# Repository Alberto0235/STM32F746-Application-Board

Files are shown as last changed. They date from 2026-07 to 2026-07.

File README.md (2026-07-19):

<div align="center">

# STM32F746ZG — Custom Application Board

**Custom-designed four-layer PCB built around the STM32F746ZGTx (LQFP-144) —
covering the full design cycle from hierarchical schematic capture to impedance-controlled layout and manufacturing outputs.**




[]()



*Alberto Marrone · Christian Schmitz · Leo Walter*
<br />
*Diseño de Circuitos Impresos (DCI) — UPV MUISE, June 2026*

<br/>

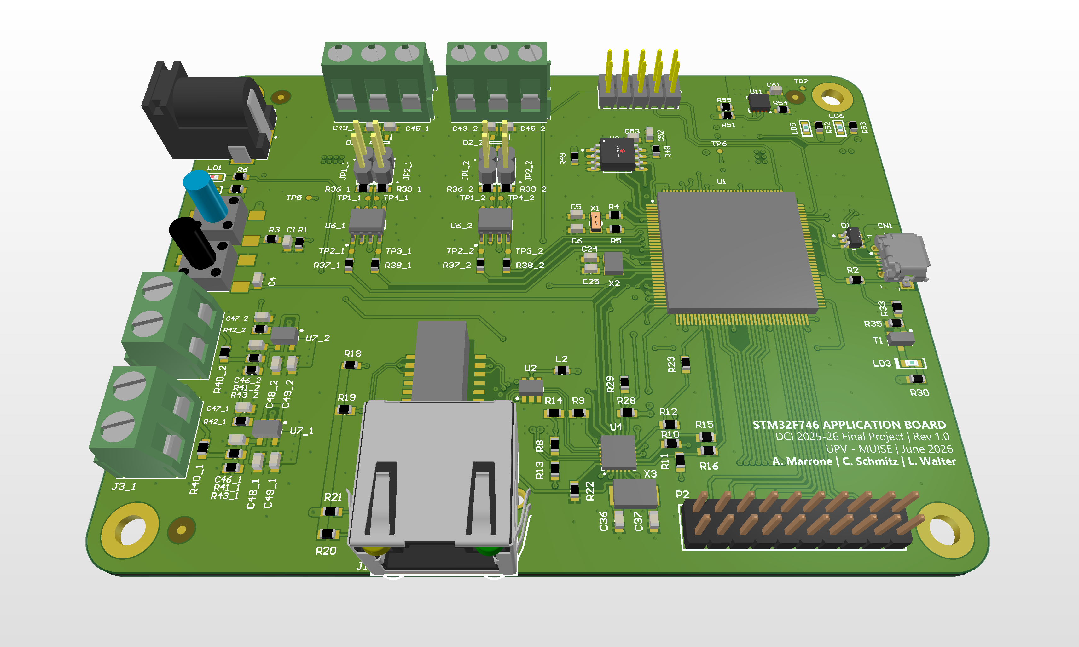
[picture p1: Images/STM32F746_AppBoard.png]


</div>

---

## Overview

This project documents the complete hardware design of a custom STM32F746ZGTx application board, derived from the [ST NUCLEO-F746ZG](https://www.st.com/en/evaluation-tools/nucleo-f746zg.html) reference design. The on-board ST-LINK debugger, Morpho/Zio expansion headers, and all peripherals not required by the project specification were removed. The remaining circuitry was redesigned and extended to implement all required interfaces on a custom four-layer PCB.

The design was carried out by a **three-person team** using **Altium Designer 26** with **Altium 365**, which provided real-time cloud-based concurrent editing, integrated version control, and design review workflows natively within the tool — enabling all three team members to work on the same project simultaneously without file conflicts.

> **Note:** This board was designed as an academic project and has not been fabricated or assembled. This repository is a static export of the completed design; the Altium 365 cloud workspace is not linked here.

---

## ⚙️ Interfaces

| Block | Implementation |
|---|---|
| **Microcontroller** | STM32F746ZGTx, LQFP-144, direct-solder |
| **Ethernet** | LAN8742A-CZ-TR PHY (RMII), KMS-1102NL magnetics, KRJ-CB4.2GYZNL RJ45 |
| **USB** | Micro-AB OTG FS (Molex 475900001), ESDA6V1BC6 ESD protection, STMPS2151STR VBUS switch |
| **CAN** | 2× CAN transceiver channels, switchable 120 Ω termination, complex hierarchy |
| **Analog inputs** | 2× 0–10 V → 3.3 V conditioning channels, MCP6021 op-amp, complex hierarchy, ADC3 |
| **SPI Flash** | SST26VF032BA-104I/SM, 32 Mbit (4 MB), SOIJ-8, SPI mode |
| **GPIO expansion** | Würth 61301621121, 2×8 100 mil pitch, 16 signals |
| **Debug** | TSW-105-07-G-D, 2×5 100 mil SWD + SWO connector |
| **Power input** | PJ-002A DC barrel jack (preferred) + USB VBUS fallback via TPS2113A mux |
| **5 V rail** | LD1117S50TR LDO from VIN |
| **3.3 V rail** | LD39050PU33R LDO from 5 V bus |
| **BOOT0** | 10 kΩ pull-down + tact switch to VDD for DFU bootloader entry |
| **Clocks** | 8 MHz HSE crystal (→ PLL, 216 MHz system / 48 MHz USB), 32.768 kHz LSE (RTC) |

---

## 🧩 Schematic Architecture

The schematic is organized as a **hierarchical multi-sheet design** in Altium. A single top-level sheet instantiates all functional blocks and defines the inter-block signal connections. The CAN transceiver and ADC signal-conditioning blocks use **complex hierarchy** — one sheet per block, instantiated twice, one per channel — as required by the project specification.

<p align="center">
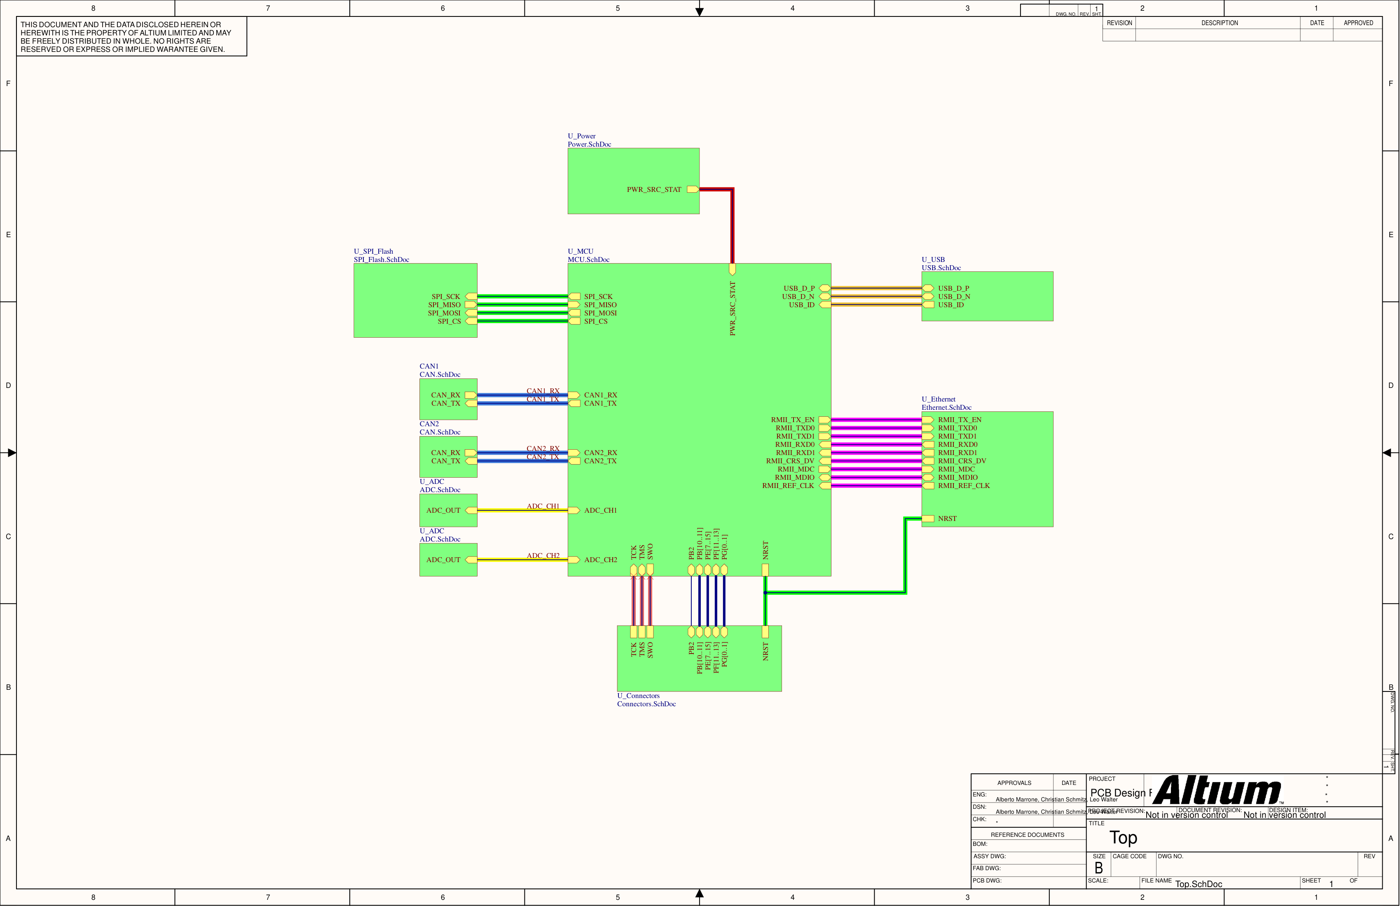
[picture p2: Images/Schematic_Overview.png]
  
</p>

### MCU Pin Allocation

Peripheral assignment was defined in STM32CubeMX and locked before schematic capture began.

<p align="center">
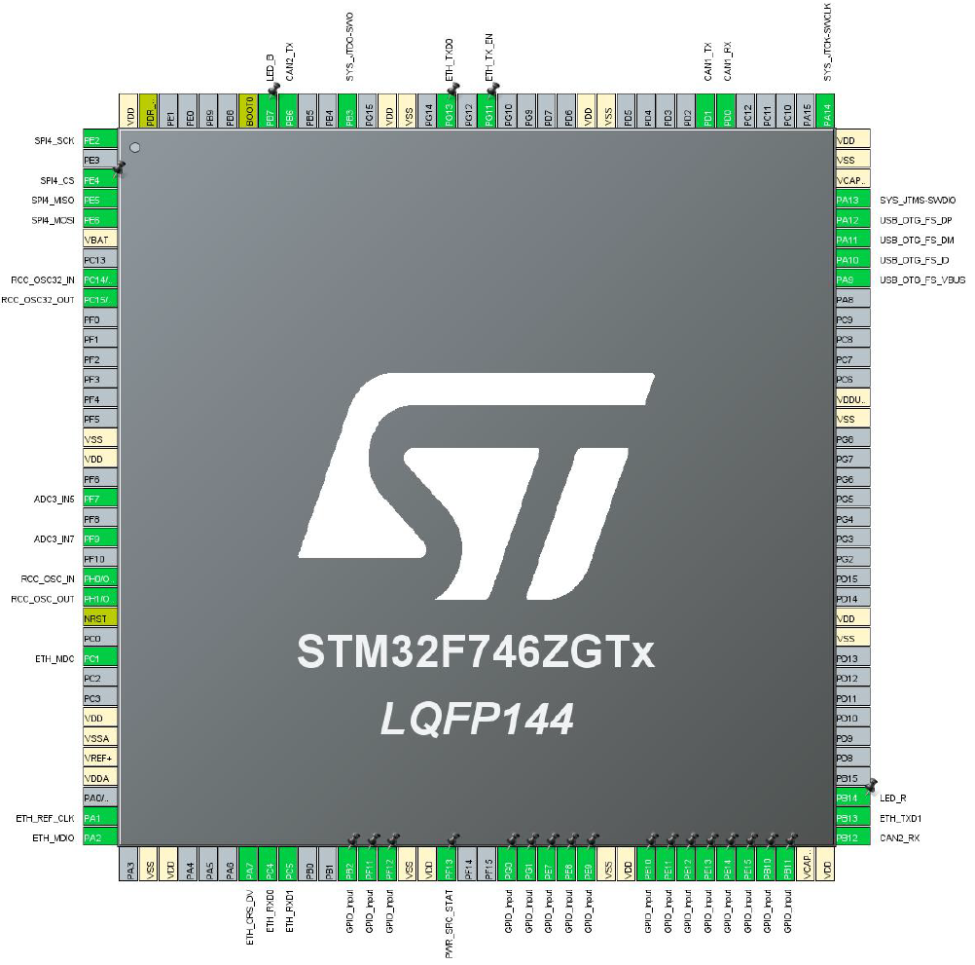
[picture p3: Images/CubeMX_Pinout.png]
  
</p>

| Peripheral | Pins |
|---|---|
| Ethernet RMII | PA1, PA2, PA7, PC1, PC4, PC5, PB13, PG11, PG13 |
| USB OTG FS | PA9 (VBUS), PA10 (ID), PA11 (DM), PA12 (DP) |
| CAN1 | PD0 (RX), PD1 (TX) |
| CAN2 | PB12 (RX), PB6 (TX) |
| SPI4 | PE2 (SCK), PE4 (CS), PE5 (MISO), PE6 (MOSI) |
| ADC3 | PF7 (IN5), PF9 (IN7) |
| SWD + SWO | PA13 (SWDIO), PA14 (SWDCLK), PB3 (SWO) |
| HSE | PH0, PH1 |
| LSE | PC14, PC15 |

The full clock tree configuration is documented in the [design report](Docs/DCI_Design_Report.pdf).

---

## 📐 PCB Stack-up

A four-layer stack-up was selected as a cost-effective balance between routing density and electrical performance. Thinner-than-standard prepregs (0.18 mm PP-021) bring the outer signal layers closer to their reference planes, yielding practical trace widths for the impedance profiles below — while keeping total board thickness within the 1.6 mm fabrication limit.

| Layer | Type | Material | Thickness | Role |
|---|---|---|---|---|
| **L1** | Signal | CF-004, 35 µm Cu | 0.04 mm | Critical signals — all high-speed components |
| | Prepreg | PP-021 | 0.18 mm | Thinned vs. standard for impedance |
| **L2** | GND Plane | CF-004, 35 µm Cu | 0.04 mm | Solid, unbroken — primary reference for L1 |
| | Core | Core-039 | 1.00 mm | FR-4 compatible dielectric |
| **L3** | Power Plane | CF-004, 35 µm Cu | 0.04 mm | Split: +3V3 / +5V regions |
| | Prepreg | PP-021 | 0.18 mm | |
| **L4** | Signal | CF-004, 35 µm Cu | 0.04 mm | Low-speed, non-critical signals only |
| **Total** | | | **1.59 mm** | Within 1.6 mm spec |

<p align="center">
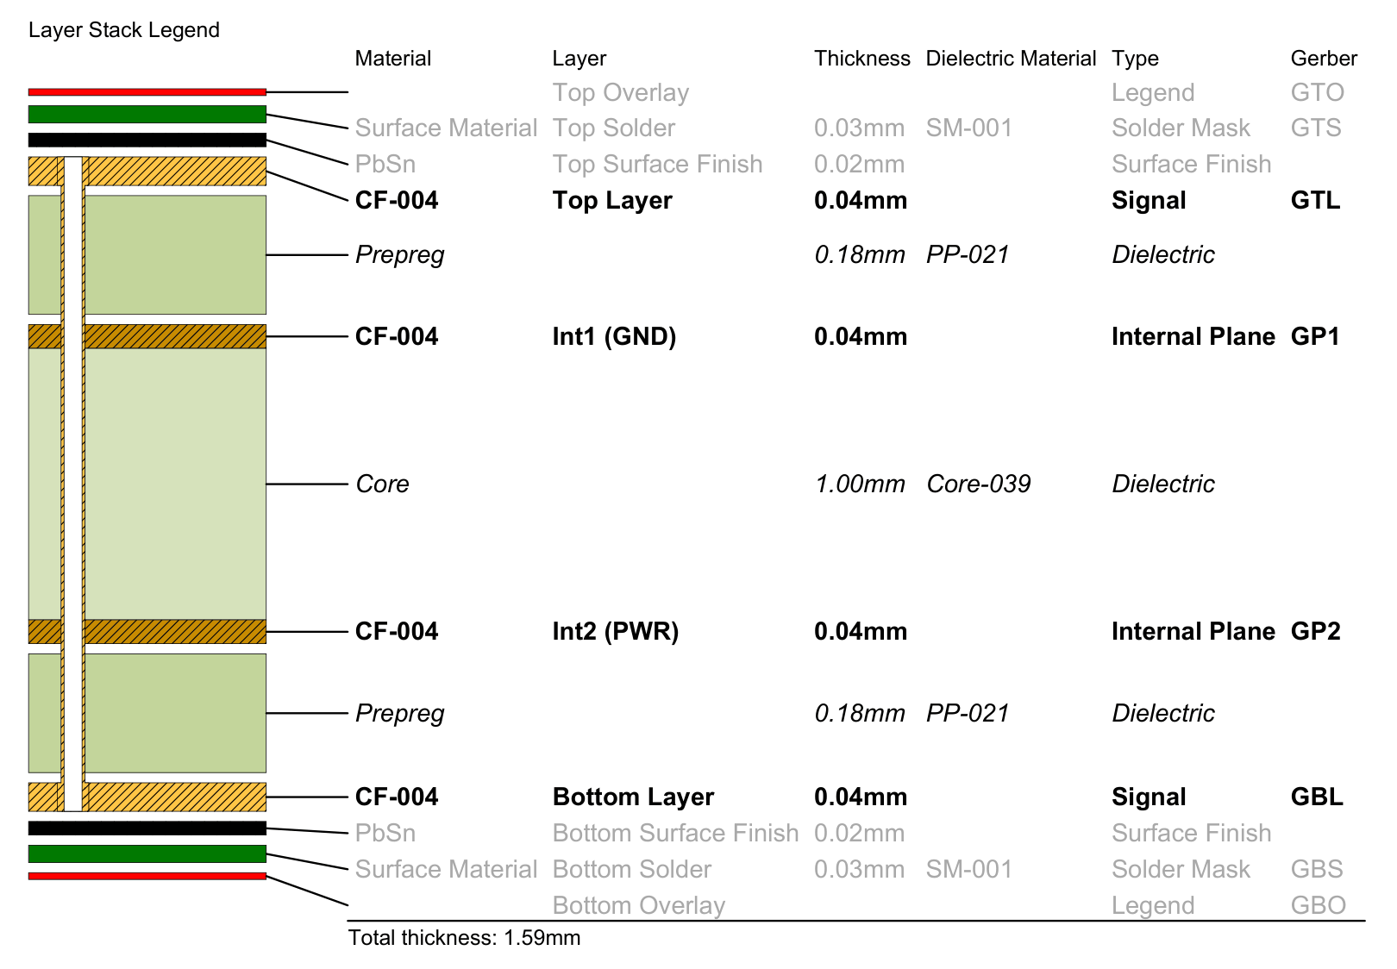
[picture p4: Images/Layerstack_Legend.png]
  
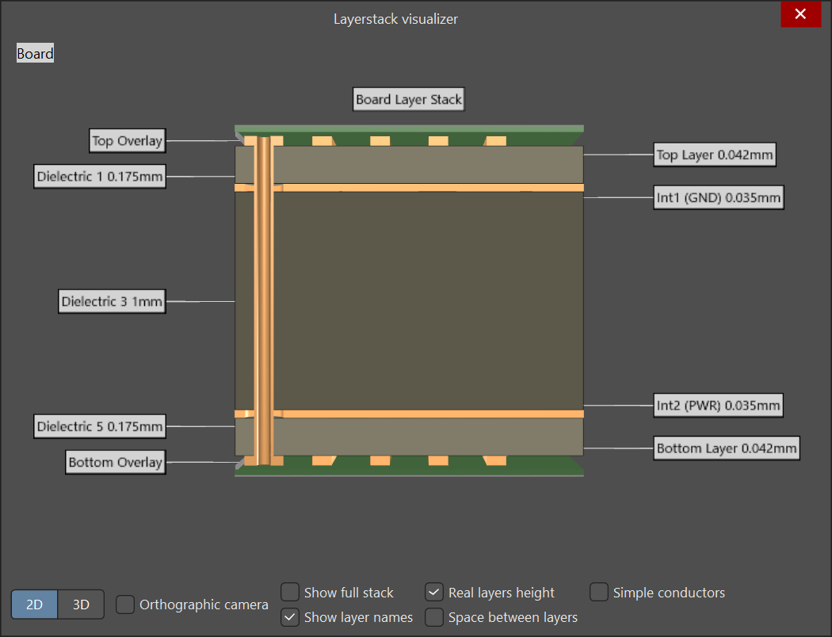
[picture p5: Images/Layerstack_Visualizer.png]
  
</p>

The stack-up is **symmetric** about the board centre to prevent warpage during lamination and reflow. All critical interfaces (Ethernet RMII, USB DP/DM, CAN H/L, SPI Flash, oscillator traces) are routed on **L1**, directly above the solid **L2 GND plane**, with their components placed on the top side to eliminate layer transitions on critical paths. L4 is reserved for low-speed signals only, since the split L3 power plane does not provide a continuous return current path.

---

## 📡 Impedance-Controlled Routing

Profiles were calculated using the Altium Layer Stack Manager and applied as routing rules to the corresponding net classes. All four profiles hit their targets within ±0.03 Ω.

| Profile | Target | Trace Width | Pair Gap | Net Class |
|---|---|---|---|---|
| `S50` | 50 Ω single-ended | 0.304 mm | — | Controlled single-ended signals |
| `D90` | 90 Ω differential | 0.222 mm | 0.155 mm | `USB_HighSpeed` — USB_DP / USB_DM |
| `D100` | 100 Ω differential | 0.170 mm | 0.160 mm | `ETH_Diff` — Ethernet RMII pairs |
| `D120` | 120 Ω differential | 0.162 mm | 0.200 mm | `CAN_Diff` — CAN_H / CAN_L |

Differential pairs are routed with intra-pair length matching enforced as Altium rules. Return-current GND vias are placed at every layer transition, and GND stitching vias surround both crystal oscillator circuits (HSE and LSE).

---

## ✅ DFM — Lab Circuits Class 5

| Measure | Purpose |
|---|---|
| Class 5 throughout (0.15 mm min clearance, 35 µm Cu) | Standard Lab Circuits process — no premium options needed |
| Through-hole vias only | No HDI — avoids sequential lamination cost and complexity |
| Symmetric 4-layer stack-up | Prevents warpage during lamination and reflow |
| 45° routing, no 90° corners | Eliminates acid traps during chemical etching |
| Teardrops at all via–trace and pad–trace junctions | Robustness against drill registration tolerances |
| Via tenting: top covered, bottom open | Prevents solder mask blistering from trapped outgassing |
| GND copper pours on both outer layers | Uniform copper distribution — consistent plating and etching |
| Thermal reliefs on all plane-connected pads | Ensures pads reach reflow temperature reliably |
| Board-level fiducials on both outer layers | Optical reference for pick-and-place alignment |
| Rectangular outline with rounded corners | Minimises milling complexity |
| All connectors along board edges | Straightforward external cable routing |
| Decoupling caps placed directly under ICs (bottom layer) | Minimises parasitic inductance, preserves L1 routing space |

---

## 🖼️ Board Renders

<p align="center">
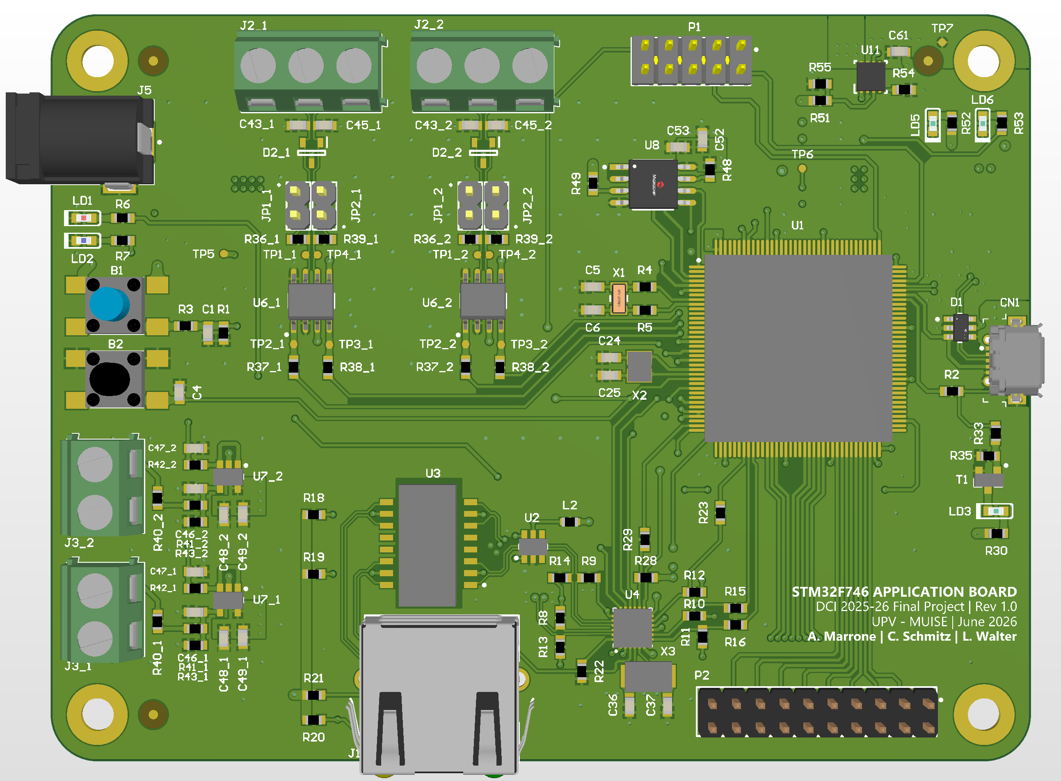
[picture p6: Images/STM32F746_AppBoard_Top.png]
  
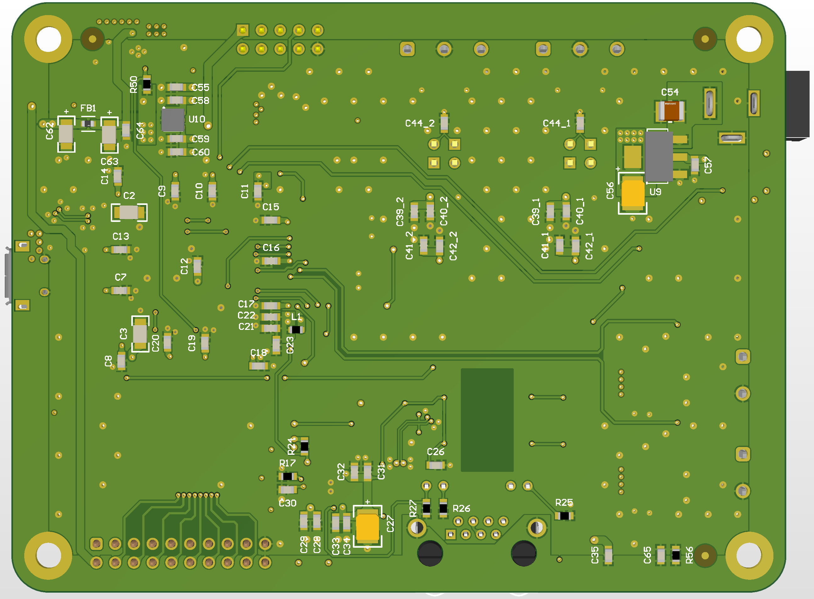
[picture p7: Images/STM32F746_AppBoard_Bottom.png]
  
</p>

**Board dimensions:** 105 × 80 mm &nbsp;|&nbsp; **Mounting holes:** 4× M3.5, 6.5 mm annular ring

---

## Manufacturing Targets

| Parameter | Value |
|---|---|
| Manufacturer | Lab Circuits, Spain |
| Manufacturing class | Class 5 |
| Total board thickness | 1.59 mm (limit: 1.6 mm) |
| Copper weight | 35 µm (1 oz) all layers |
| Surface finish | HASL lead-free |
| Solder mask | Green |
| Via technology | Standard through-hole only |

---

## Repository Structure

```
STM32F746-Application-Board/
│
├── Hardware/
│   ├── Altium/                               Altium Designer 26 project files
│   │   ├── STM32F746_AppBoard.PrjPCB
│   │   ├── STM32F746_AppBoard.PcbDoc
│   │   ├── STM32F746_AppBoard.BomDoc
│   │   ├── STM32F746_AppBoard.DwfDot
│   │   ├── STM32F746_AppBoard.PCBDwf
│   │   ├── STM32F746_AppBoard.OutJob
│   │   ├── Top.SchDoc                        Top-level hierarchical sheet
│   │   ├── MCU.SchDoc                        STM32F746ZGTx + decoupling
│   │   ├── Power.SchDoc                      Power supply and distribution
│   │   ├── USB.SchDoc                        USB OTG FS interface
│   │   ├── Ethernet.SchDoc                   LAN8742A PHY + magnetics + RJ45
│   │   ├── CAN.SchDoc                        CAN transceiver (instantiated ×2)
│   │   ├── ADC.SchDoc                        0–10 V conditioner (instantiated ×2)
│   │   ├── SPI_Flash.SchDoc                  SPI Flash memory
│   │   └── Connectors.SchDoc                 SWD + GPIO expansion
│   │
│   ├── Libraries/
│   │   ├── STM32F746_AppBoard.SchLib
│   │   └── STM32F746_AppBoard.PcbLib
│   │
│   ├── CubeMX/
│   │   └── STM32F746_AppBoard.ioc
│   │
│   └── Exports/
│       ├── Schematic.pdf
│       └── Draftsman.pdf
│
├── Manufacturing/
│   ├── Gerbers/
│   │   └── Gerber_STM32F746_AppBoard.zip
│   └── Assembly/
│       ├── BOM_STM32F746_AppBoard.xlsx
│       └── PickPlace_STM32F746_AppBoard.csv
│
├── Docs/
│   └── DCI_Design_Report.pdf
│
├── Images/
│   ├── STM32F746_AppBoard.png
│   ├── STM32F746_AppBoard_Top.png
│   ├── STM32F746_AppBoard_Bottom.png
│   ├── Schematic_Overview.png
│   ├── CubeMX_Pinout.png
│   ├── Layerstack_Visualizer.png
│   └── Layerstack_Legend.png
│
├── .gitignore
├── LICENSE
└── README.md
```

---

## 📥 Downloads

| File | Description |
|---|---|
| [Schematic (PDF)](Hardware/Exports/Schematic.pdf) | Full schematic — all hierarchical sheets |
| [Draftsman (PDF)](Hardware/Exports/Draftsman.pdf) | Stack-up, layer views, board outline |
| [Design Report (PDF)](Docs/DCI_Design_Report.pdf) | Stack-up analysis, impedance profiles, DFM decisions |
| [BOM (xlsx)](Manufacturing/Assembly/BOM_STM32F746_AppBoard.xlsx) | Bill of materials |
| [Pick & Place (csv)](Manufacturing/Assembly/PickPlace_STM32F746_AppBoard.csv) | Assembly centroid data |
| [Gerbers](Manufacturing/Gerbers/Gerber_STM32F746_AppBoard.zip) | Production-ready Gerber X2 |
| [CubeMX Config (.ioc)](Hardware/CubeMX/STM32F746_AppBoard.ioc) | STM32CubeMX pin assignment and clock tree |

---

## 👥 Team

This project was developed as a three-person team for the *Diseño de Circuitos Impresos* (DCI) course at **Universitat Politècnica de València (UPV)**, MUISE programme, academic year 2025–26. Real-time concurrent editing and design review were managed through **Altium 365**.

| | Name | |
|---|---|---|
| 🇮🇹 | Alberto Marrone |  |
| 🇩🇪 | Christian Schmitz |  |
| 🇩🇪 | Leo Walter |  |

---

## References

- Lab Circuits — [Multilayer manufacturing parameters, Class 5](https://www.lab-circuits.com/es/fabricacion-multicapa)
- STMicroelectronics — STM32F746ZGTx Datasheet and Reference Manual
- STMicroelectronics — AN2867: Oscillator design guide for STM32 microcontrollers
- STMicroelectronics — NUCLEO-F746ZG User Manual (UM1974)
- *Diseño de Circuitos Impresos* — UPV course material

---

## License

Released under the [MIT License](LICENSE).
`Copyright (c) 2026 Alberto Marrone, Christian Schmitz, Leo Walter`

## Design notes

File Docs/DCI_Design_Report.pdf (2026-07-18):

### DCI Final Project

Alberto Marrone, Christian Schmitz, Leo Walter

Submission date: 15 June 2026

### 1 Objective

The objective of this report is to summarize the selected PCB stack-up, the component placement strategy, the routing approach and the main design-for-manufacturing decisions.

The final design is based on the STM32F746ZGTx microcontroller in an LQFP144 package. The PCB includes USB, Ethernet, two CAN interfaces, SPI flash memory, two analog input channels, GPIO connectors, a debug connector and the required power supply circuitry.

The goal was to keep the PCB manufacturable with standard LabCircuits capabilities while still providing good routing space, reliable signal return paths and suitable impedance-controlled routing for the critical interfaces.

### 2 Hardware Overview

The main functional blocks of the PCB are:

- STM32F746ZGTx microcontroller in LQFP144 package.
- USB OTG FS interface with Micro-AB connector and ESD protection.
- Ethernet interface using RMII signals, Ethernet PHY and RJ45 connector.
- Two CAN interfaces with CAN transceivers and differential CAN lines.
- SPI flash memory connected through SPI4.
- Two analog inputs connected to ADC3 channels.
- GPIO connector and SWD debug connector.
- Power supply from external DC input or USB VBUS.

The power supply uses two possible input sources. The external DC input is used as the preferred source, while USB VBUS can be used as a fallback source. A power multiplexer selects the active source for the 5 V rail. The 3.3 V rail is generated from the 5 V rail and supplies the MCU, Ethernet PHY and logic circuits.

### 3 Schematic Documentation

The schematic was organized hierarchically in Altium. The top-level schematic connects the functional blocks, including MCU, power supply, USB, Ethernet, CAN, ADC, SPI flash and connectors. This makes the design easier to read and keeps the individual schematic pages simple. The complete schematic is included as part of the project documentation. The most important schematic overview is shown in Figure 1.

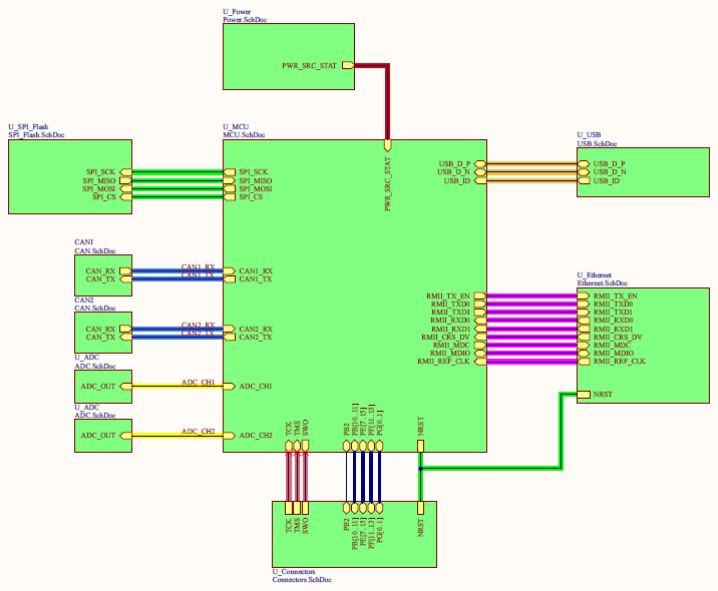
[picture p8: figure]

Figure 1: Top-level schematic showing the hierarchical project structure.

### 4 STM32CubeMX and IOC Configuration

The STM32CubeMX configuration file (.ioc) is included with the final project files. It documents the selected MCU, the pin assignment and the clock configuration used for the design.

The selected MCU is the STM32F746ZGTx in the LQFP144 package. The pinout was configured for the required project interfaces, including USB OTG FS, Ethernet RMII, CAN1, CAN2, SPI4, ADC3, SWD debug pins and GPIO signals.

The MCU pinout is shown in Figure 2. The clock tree is shown in Figure 3. The clock tree confirms the clock configuration used in CubeMX and provides the basis for the peripheral configuration.


Figure 2: STM32CubeMX MCU pinout for the STM32F746ZGTx.

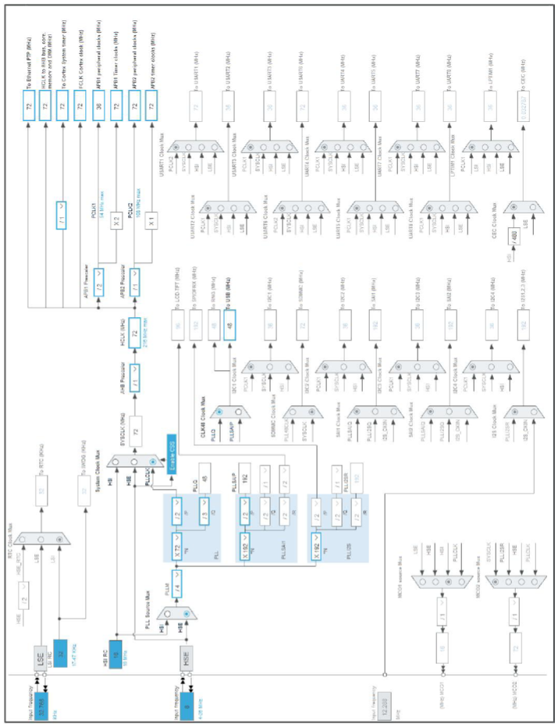
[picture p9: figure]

Figure 3: STM32CubeMX clock tree configuration.

### 5 PCB Stack-up

A four-layer PCB was selected as a compromise between cost, routing density and electrical performance. A two-layer board would be cheaper, but it would make routing and signal return paths more difficult. A six-layer board would provide more routing freedom, but the additional cost is not necessary for this project.

The selected layer structure is:

Signal Top (L1) – GND (L2) – Power (L3) – Signal Bottom (L4)

The top layer is used for the main components and for critical signal routing. The second layer is a continuous ground plane, which provides a good return path for signals routed on the top layer. The third layer is used for power distribution and is split into different voltage regions. The bottom layer is mainly used for secondary routing and less critical signals.

Because the power plane is split, the bottom layer does not always have an ideal continuous reference plane. Therefore, critical interfaces such as USB, Ethernet and CAN are preferably routed on the top layer, directly above the continuous ground plane.

The final stack-up has a total thickness of approximately 1.59 mm. The main stack-up is:

- Top Layer: signal layer, approximately 0.04 mm copper.
- Prepreg: approximately 0.18 mm.
- Internal Layer 1: continuous GND plane, approximately 0.04 mm copper.
- Core: approximately 1.00 mm.
- Internal Layer 2: power plane, approximately 0.04 mm copper.
- Prepreg: approximately 0.18 mm.
- Bottom Layer: signal layer, approximately 0.04 mm copper.

Standard FR-4 material was selected, since the frequencies in this project do not require special high-frequency material.

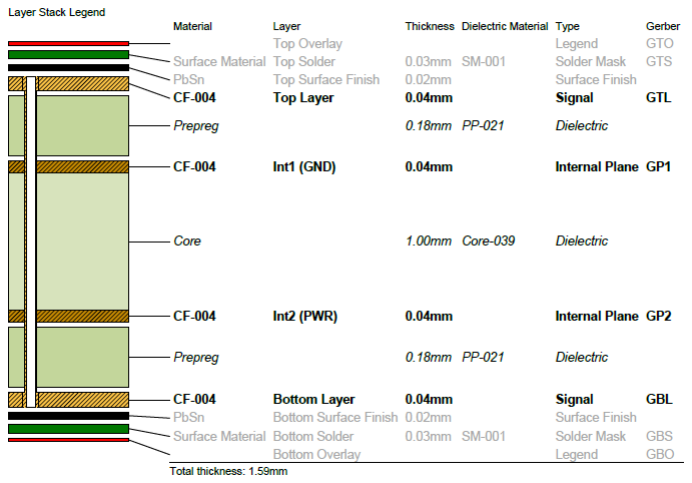
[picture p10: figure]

Figure 4: Selected four-layer PCB stack-up in Altium.

### 6 Impedance Profiles and Design Rules

The required impedance profiles were created in the Altium Layer Stack Manager. These profiles are used to define routing rules for controlled-impedance traces and differential pairs.

A 50 Ohm single-ended profile was created for signals that require controlled impedance. Differential pair profiles were created for USB, Ethernet and CAN routing.

The final calculated impedance profiles are:

- Single-ended profile: target 50 Ohm, calculated 50.01 Ohm.
- USB differential pair: target 90 Ohm, calculated 89.98 Ohm.
- Ethernet differential pair: target 100 Ohm, calculated 100.02 Ohm.
- CAN differential pair: target 120 Ohm, calculated 119.97 Ohm.

The general design rules were defined according to LabCircuits Class 5. Minimum track width, clearance, via dimensions and solder-mask parameters were selected to stay within standard manufacturing limits. Wider traces were used for power nets where possible, while standard signal widths were used for general low-speed routing.

Dedicated net classes were created for different signal groups, for example power nets, differential pairs and general signals. This makes the routing rules easier to apply and reduces the risk of using unsuitable track widths or clearances.

### 7 LabCircuits Manufacturing Class

The PCB was designed according to LabCircuits Class 5. This class was selected because it offers sufficiently small track widths and clearances for the routing around the 144-pin LQFP microcontroller while still remaining a standard and cost-effective manufacturing option.

The selected stack-up, copper thicknesses, minimum track widths and clearances are compatible with this class. Therefore, no special high-cost manufacturing options are required.

### 8 Component Placement

The placement was developed using a functional-block approach. Components that belong to the same circuit function were placed close together. This reduces trace length and simplifies routing.

The microcontroller was placed in the right-central area of the board, which provides short connections to the surrounding interfaces. The Ethernet interface is placed close to the RJ45 connector, and the USB circuit is placed close to the USB connector. The two CAN circuits and analog input circuits are grouped close to their external connectors. This keeps the routing compact and reduces unnecessary crossing of signals.

The final board size is approximately 105 mm by 80 mm. The board outline is rectangular with rounded corners. Four mounting holes are placed close to the board corners.

Connectors such as USB, Ethernet, power input, screw terminals, GPIO and debug connector are placed near the board edges to allow easy access from outside the PCB.

The differential interfaces were placed so that USB, Ethernet and CAN signals can be routed as directly as possible. Critical components and signals were kept on the top layer whenever possible, because the top layer has the continuous ground plane directly underneath it.

Analog circuitry was kept away from noisy digital and power-switching regions. Instead of splitting the ground plane, the separation was mainly achieved by careful placement and routing. This keeps the ground plane continuous and avoids unnecessary interruptions of signal return paths.

Decoupling capacitors were placed as close as possible to their corresponding IC supply pins. Where possible, capacitors were placed directly below or close to the related ICs to reduce parasitic inductance and improve high-frequency decoupling.

Some low-speed support circuitry was placed on the bottom layer to reduce routing congestion on the top layer.

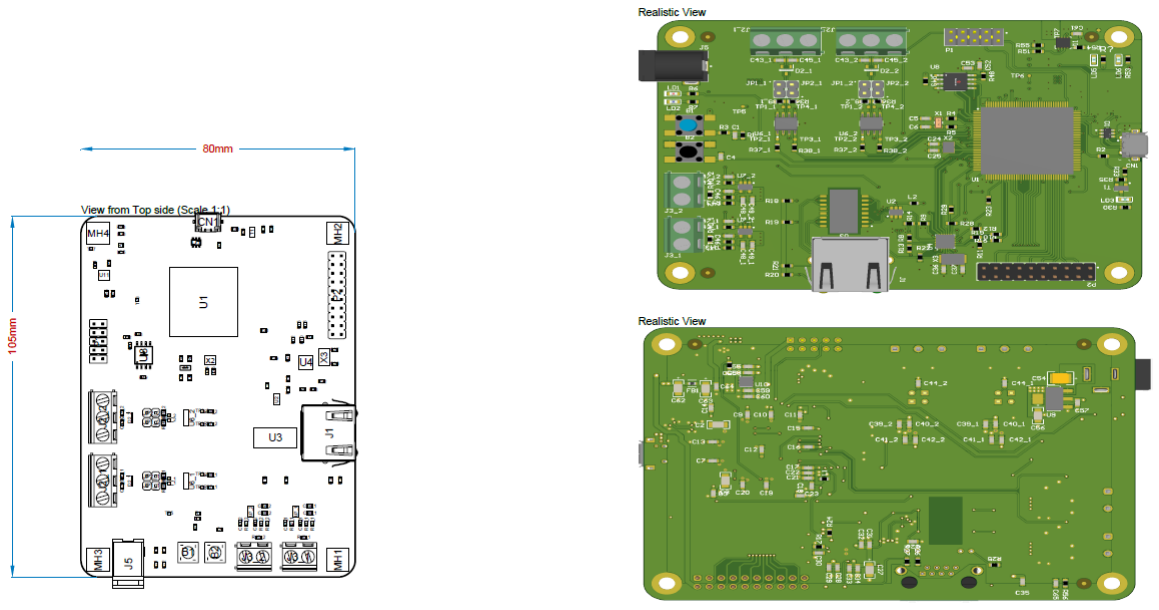
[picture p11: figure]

Figure 5: Final PCB component placement.

### 9 Routing and DFM Considerations

The routing was done with standard manufacturing methods in mind. The goal was to avoid unnecessary complexity and to keep the board suitable for reliable fabrication and assembly.

### 9.1 Board Outline and Connectors

The PCB uses a simple rectangular board outline with rounded corners. This avoids unnecessary milling complexity. Mounting holes are placed near the corners with sufficient clearance to surrounding components.

The main connectors are placed near the board edges. This makes external cabling easier and improves mechanical accessibility.

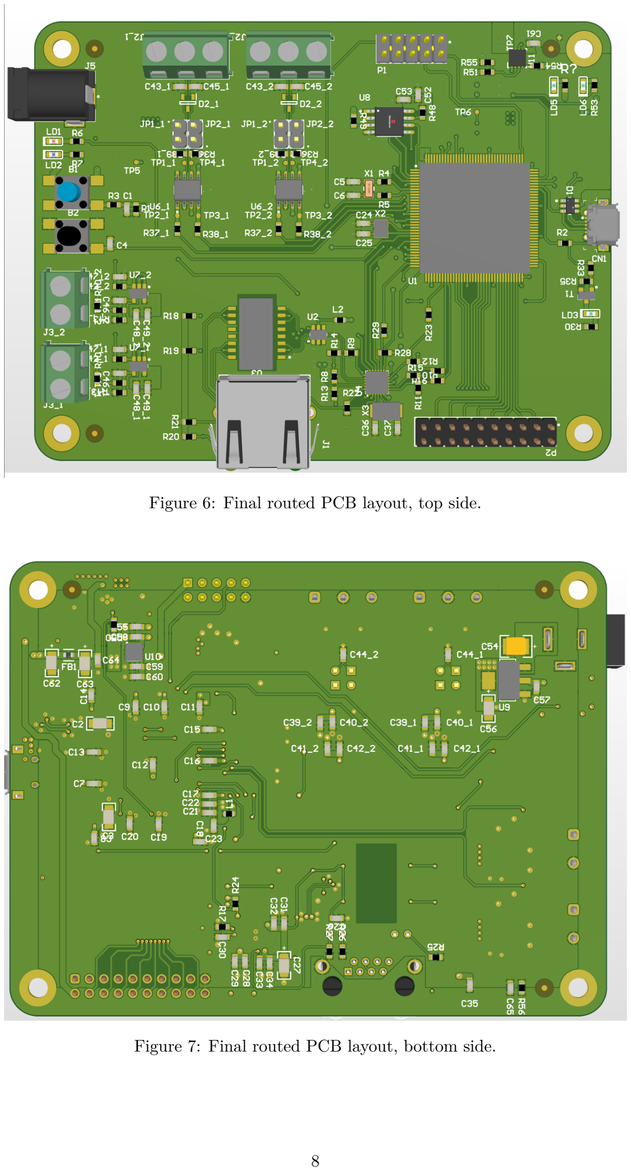
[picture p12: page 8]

Figure 6: Final routed PCB layout, top side.

Figure 7: Final routed PCB layout, bottom side.

### 9.2 Via Technology

Only standard through-hole vias were used. No microvias, blind vias or buried vias are required. This keeps the manufacturing process simple and avoids additional cost.

### 9.3 Symmetric Stack-up

The four-layer stack-up was designed to be symmetric. A symmetric stack-up reduces the risk of board warpage during lamination and soldering. This improves mechanical stability and assembly reliability.

### 9.4 Copper Pours

Ground copper pours were added on the outer layers. They help to create a more uniform copper distribution and provide additional ground connection areas. A more uniform copper distribution also helps during manufacturing, because it reduces the risk of uneven etching or plating.

### 9.5 Thermal Reliefs

Thermal reliefs were used for pads connected to copper planes. This makes soldering easier because the pad is not directly connected to a large copper area. Without thermal reliefs, the copper plane could remove too much heat from the pad, which may lead to poor solder joints.

### 9.6 Trace Routing

Traces were routed mainly with 45-degree angles. Sharp 90-degree corners were avoided because they are not good practice for PCB routing and can create unnecessary manufacturing and signalintegrity issues.

Differential pairs were routed with controlled width and spacing according to the calculated impedance profiles. Unnecessary vias and layer changes were avoided on critical signal paths where possible.

### 9.7 Teardrops

Teardrops were added at via-to-trace and through-hole pad-to-trace transitions. This increases the copper area at these transitions and makes the connection more robust against drilling and etching tolerances.

### 9.8 Via Tenting

Vias were tented on the top side. The bottom side was left open to avoid trapping gases during manufacturing. This reduces the risk of solder mask defects such as blistering.

### 9.9 Fiducials

Board-level fiducials were placed on the outer layers. They are used by pick-and-place machines as optical reference points during automated assembly.

### 10 Critical Analysis

The main advantage of the design is the continuous ground plane directly below the top layer. This provides a good return path for critical signals and improves signal integrity. The four-layer stack-up also gives enough routing space while keeping the cost lower than a six-layer board.

Another advantage is that only standard manufacturing technologies are used. The design uses LabCircuits Class 5, standard FR-4 material and standard through-hole vias. No HDI technologies are required.

The main weakness is that the bottom layer uses the split power plane as its reference. Therefore, it is not ideal for critical signals. This was mitigated by placing and routing important interfaces on the top layer whenever possible.

The board size of approximately 105 mm by 80 mm provides enough routing space for the MCU, connectors and interfaces. A smaller PCB would reduce manufacturing cost, but it would also make the placement and routing around the 144-pin MCU, Ethernet interface and connectors more difficult.

Overall, the selected stack-up, placement and routing strategy provide a practical compromise between cost, manufacturability and electrical performance.

### 11 Conclusion

A four-layer PCB with the structure Signal – GND – Power – Signal was selected. This provides a good balance between cost and performance. The continuous ground plane below the top layer is the most important feature for signal integrity.

The final stack-up has a total thickness of approximately 1.59 mm and uses standard FR-4 based materials. The required impedance profiles for 50 Ohm single-ended routing and 90 Ohm, 100 Ohm and 120 Ohm differential routing were created in Altium and used for the corresponding routing rules.

The final design is based on the STM32F746ZGTx microcontroller and includes USB, Ethernet, two CAN interfaces, SPI flash, ADC inputs, GPIO and power management. The IOC file is included with the final project documentation and documents the MCU pinout and clock tree configuration. The schematic documentation is also included to show the electrical structure of the design.

The PCB was designed according to LabCircuits Class 5 and uses standard manufacturing options. The routing avoids unnecessary complexity and includes several DFM measures such as a simple board outline, standard vias, thermal reliefs, teardrops, copper pours and fiducials.

### References

- Lab Circuits, ‘4 Layers, 1.6 mm, Build-up 1”, available at: https://www.lab-circuits.com/uploads/doc/multicapa/4layers_1.6mm_LabCode1.pdf (https://www.lab-circuits.com/uploads/doc/multicapa/4layers_1.6mm_LabCode1.pdf)
- Lab Circuits, ‘Fabricacion multicapa – parametros de fabricacion”, available at: https://www.lab-circuits.com/es/fabricacion-multicapa
- Diseno de Circuitos Impresos, UPV course slides.
- STMicroelectronics, STM32F746ZGTx datasheet and STM32CubeMX configuration report.
- Altium Designer PCB schematic, fabrication and assembly output files of the final project.

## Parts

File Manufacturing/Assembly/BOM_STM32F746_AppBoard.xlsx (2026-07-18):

Line # | Name | Description | Designator | Quantity | Manufacturer 1 | Manufacturer Part Number 1 | Supplier 1 | Supplier Part Number 1 | Footprint
 | 475900001 |  | CN1 | 1 | Molex | 47590-0001 | Arrow Electronics | 0475900001 | MOLEX_47590001
 |  |  | JP1_1, JP1_2, JP2_1, JP2_2 | 4 | TE Connectivity | 8266462 | Arrow Electronics | 826646-2 | HDR_1x2_2R54_V_M_S
 | USBLC6-4SC6 |  | U2 | 1 | STMicroelectronics | USBLC6-4SC6 | Arrow Electronics | USBLC6-4SC6 | SOT23-6L
 | LD1117S50TR |  | U9 | 1 | STMicroelectronics | LD1117S50TR | Arrow Electronics | LD1117S50TR | SOT-223
 | LD39050PU33R |  | U10 | 1 | STMicroelectronics | LD39050PU33R | Arrow Electronics | LD39050PU33R | DFN6_0R95_3x3_TP
 | 691213710002 | 213 Series 5MM Pitch Straight, Pcb Terminal Block, Through Hole, 2 Way | J3_1, J3_2 | 2 | Wurth Elektronik | 691213710002 | DigiKey | 732-2038-ND | 691213710002
 | 691213710003 | 213 Series 5MM Pitch Straight, Pcb Terminal Block, Through Hole, 3 Way | J2_1, J2_2 | 2 | Wurth Elektronik | 691213710003 | DigiKey | 732-2039-ND | 691213710003
 | STM32F746ZGT7 | ARM Cortex-M4 32-bit MCU+FPU, 1024 KB Flash, 320 KB Internal RAM, 114 I/Os, 144-Pin LQFP, -40 to 105 degC, Tray | U1 | 1 | STMicroelectronics | STM32F746ZGT7 | Mouser | 511-STM32F746ZGT7 | STM-LQFP144_M
 | CL32B106KBJNNNE | Cap Ceramic 10uF 50V X7R ±10% SMD 1210 +125°C Embossed T/R | C54 | 1 | Samsung Electro-Mechanics | CL32B106KBJNNNE | Arrow Electronics | CL32B106KBJNNNE | FP-CL32-IPC_C
 | 100n | Capacitor | C1, C4, C7, C8, C9, C10, C11, C13, C14, C15, C16, C17, C18, C19, C20, C22, C23, C26, C30, C31, C32, C33, C34, C35, C40_1, C40_2, C42_1, C42_2, C47_1, C47_2, C49_1, C49_2, C53, C57, C58, C60, C61, C64 | 38 | Yageo Group | C0603C104J1RACAUTO7411 | Mouser | 80-C0603C104J1RAUTO7 | 0603C
 | 2p0 | Capacitor | C5, C6 | 2 | Murata | GQM1875C2E2R0BB12D | Mouser | 81-GQM1875C2E2R0BB2D | 0603C
 | 4u7 | Capacitor | C12, C39_1, C39_2, C41_1, C41_2, C48_1, C48_2 | 7 | Murata | GRM188Z71C475KE21D |  |  | 0603C
 | 1u0 | Capacitor | C21, C29, C52, C55, C59 | 5 | TDK | C1608X7R1C105K080DC | DigiKey | 445-C1608X7R1C105K080DCCT-ND | 0603C
 | 4p3 | Capacitor | C24, C25 | 2 | Yageo Group | CC0603CRNPO9BN4R3 | Arrow Electronics | CC0603CRNPO9BN4R3 | 0603C
 | 33p | Capacitor | C43_1, C43_2, C45_1, C45_2 | 4 | Vishay | VJ0603A330JXAAC | DigiKey | 720-1913-1-ND | 0603C
 | 4n7 | Capacitor | C44_1, C44_2 | 2 | Yageo Group | C0603C472K5GACTU | Arrow Electronics | C0603C472K5GACTU | 0603C
 | 1n0 | Capacitor | C65 | 1 | Yageo Group | C0603C102K5RACTM | Mouser | 80-C0603C102K5RACTM | 0603C
 | 470p | Capacitor 0402 / 0603 / 0805 | C28 | 1 | Yageo Group | C0603C471K1RALTU | Mouser | 80-C0603C471K1RAL | 0603C
 | 30p | Capacitor 0402 / 0603 / 0805 | C36, C37 | 2 | Yageo Group | C0603C300K5RACTU | Mouser | 80-C0603C300K5RACTU | 0603C
 | 6n8 | Capacitor 0402 / 0603 / 0805 | C46_1, C46_2 | 2 | Murata | GCM1885C2A682GE02J | Mouser | 81-GCM1885C2A682GE2J | 0603C
 | 2u2 | Capacitor,2.2uF,16V, X7R,10%,0805,YAGEO | C2, C3, C62, C63 | 4 | Murata | GRM188Z71E225ME43D | Mouser | 81-GRM188Z71E225ME3D | TAN-A
 | BLM18SG121TZ1D | Chip Ferrite Bead, 0603, 120Ω @ 100MHz, 25%, 0.025Ω, 3A | FB1 | 1 | Murata | BLM18SG121TZ1D | Mouser | 81-BLM18SG121TZ1D | FP-BLM18-0_15-t0_5-d1_2-MFG
 | ABS07-120-32.768KHZ-T | Crystal | X1 | 1 | Abracon | ABS07-120-32.768KHZ-T | DigiKey | 535-11937-1-ND | XTAL_2SM_3R2X1R5
 | ABM8AAIG-8.000MHz-V2R-T3 | Crystal Oscillator | X2 | 1 | Abracon | ABM8AAIG-8.000MHZ-V2R-T3 | Mouser | 815-AAIG8000MHZV2RT | OSC_2SM_3R2x2R5
 | ECS-250-12-30Q-JES-TR | Crystal Oscillator | X3 | 1 | ECS International | ECS-250-12-30Q-JES-TR | Mouser | 520-ECS2501230QJESTR | XTAL_2SM_5R0X3R2
 | TPS2113ADRBR | Dual In / Single Out Autoswitching Power Mux, 2.8 to 5.5 V, -40 to 85 degC, 9-pin SON (DRB), Green (RoHS & no Sb/Br) | U11 | 1 | Texas Instruments | TPS2113ADRBR | Arrow Electronics | TPS2113ADRBR | DRB0008B_V
 | SST26VF032BA-104I/SM | IC FLASH 32MBIT SPI/QUAD 8SOIJ | U8 | 1 | Microchip | SST26VF032BA-104I/SM | Mouser | 579-T26VF032BA104ISM | FP-C04-056-IPC_A
 | TCAN1051HVDR | IC TRANSCEIVER HALF 1/1 8SOIC | U6_1, U6_2 | 2 | Texas Instruments | TCAN1051HVDR | DigiKey | 296-44226-6-ND | FP-D0008B-IPC_B
 | BEAD | Inductor | L1, L2 | 2 | TDK | MPZ1608S121ATDH5 | Arrow Electronics | MPZ1608S121ATDH5 | 0603L
 | LAN8742A-CZ-TR | LAN8742A-CZ-TR - Small Footprint RMII 10/100 Ethernet, Transceiver with HP Auto-MDIX and flexPWR Technology SQFN-24 | U4 | 1 | Microchip | LAN8742A-CZ-TR | Arrow Electronics | LAN8742A-CZ-TR | QFN24_0R5_4X4
 | 615008137421 | Modular Jack WR-MJ, Tab Up, Shielded, with LED and EMI Panel Finger, Horizontal Entry, THT, 8P8C | J1 | 1 | Wurth Elektronik | 615008137421 | DigiKey | 732-2112-ND | 615008137421
 | MCP6021T-E/OT | None | U7_1, U7_2 | 2 | Microchip | MCP6021T-E/OT | Avnet | MCP6021T-E/OT | SOT-23-OT5_N
 | MMBTA05LT3G | NPN Bipolar Transistor | T1 | 1 | onsemi | MMBTA05LT3G | Arrow Electronics | MMBTA05LT3G | SOT-23
 | TSW-105-07-G-D | Post Terminal Strip Assembly, Pitch 2.54 mm, 2 x 5 Position, Height 8.58 mm, Tail Length 2.54 mm, -55 to 125 degC, RoHS, Bulk | P1 | 1 | Samtec | TSW-105-07-G-D | Avnet | TSW-105-07-G-D | SMTC-TSW-105-07-G-D_V
 | H1102NL | replaces the KMS-1102NL | U3 | 1 | Yageo Group | H1102NL | Avnet | H1102NL | Transformer
 | 10K | Resistor | R1, R2, R10, R11, R12, R17, R27, R28, R43_1, R43_2, R48, R49 | 12 | Panasonic | ERJS03F1002V | Mouser | 667-ERJ-S03F1002V | 0603R
 | 330R | Resistor | R3, R30 | 2 | Yageo Group | RC0603FR-13330RL | Arrow Electronics | RC0603FR-13330RL | 0603R
 | 0R0 | Resistor | R4, R5 | 2 | Panasonic | ERJ-S030R00V | Mouser | 667-ERJ-S030R00V | 0603R
 | 1K0 | Resistor | R6, R40_1, R40_2, R52 | 4 | Bourns | CR0603-FX-1001EPF | Mouser | 652-CR0603FX1001EPF | 0603R
 | 680R | Resistor | R7 | 1 | Panasonic | ERJ-S03F6800V | Mouser | 667-ERJ-S03F6800V | 0603R
 | 33R | Resistor | R15, R16, R23, R29, R37_1, R37_2, R38_1, R38_2 | 8 | Panasonic | ERJ-S03J330V | Mouser | 667-ERJ-S03J330V | 0603R
 | 75R | Resistor | R18, R19, R20, R21 | 4 | Panasonic | ERJ-S03F75R0V | Mouser | 667-ERJ-S03F75R0V | 0603R
 | 47K | Resistor | R33 | 1 | Vishay | CRCW060347K0FKED | Mouser | 71-CRCW060347K0FKED | 0603R
 | 22K | Resistor | R35, R41_1, R41_2, R55 | 4 | TE Connectivity | CRGP0603F22K | Newark | CRGP0603F22K | 0603R
 | 60R4 | Resistor | R36_1, R36_2, R39_1, R39_2 | 4 | Vishay | CRCW060360R4FKTA | Farnell | CRCW060360R4FKTA | 0603R
 | 100R | Resistor | R42_1, R42_2 | 2 | Yageo Group | TR0603MR-07100RL | Mouser | 603-TR0603MR-07100RL | 0603R
 | 100K | Resistor | R50, R51 | 2 | Vishay | CRCW0603100KFKED | Mouser | 71-CRCW0603100KFKED | 0603R
 | 390R | Resistor | R54 | 1 | Panasonic | ERJPA3F3900V | Newark | ERJPA3F3900V | 0603R
 | 1M0 | Resistor | R56 | 1 | Panasonic | ERJ-S03F1004V | DigiKey | 10-ERJ-S03F1004VCT-ND | 0603R
 | 270R | Resistor 0402 / 0603 / 0805 | R25, R26 | 2 | Yageo Group | TR0603NR-07270RL | Mouser | 603-TR0603NR-07270RL | 0603R
 | 470R | Resistor 0402 / 0603 / 0805 | R53 | 1 | Yageo Group | RE0603DRE07470RL | Mouser | 603-RE0603DRE07470RL | 0603R
 | 1K5 | Resistor,1K5,0402,1%,YAGEO | R24 | 1 | Yageo Group | AC0603FR-071K5L | Arrow Electronics | AC0603FR-071K5L | 0603R
 | 12K1 | Resistor,12K1,0603,1%,VISHAY | R22 | 1 | Yageo Group | RE0603FRE0712K1L | Mouser | 603-RE0603FRE0712K1L | 0603R
 | 50R | Resistor,50,0603,1%,YAGEO | R8, R9, R13, R14 | 4 | Vishay | FC0603E50R0BST1 | Mouser | 71-FC0603E50R0BST1 | 0603R
 | BOOT0 Button | SE PUSHBUTTON | B1 | 1 | Same Sky | TS40-66-33-BK-160-SMT-TR | Mouser | 179-TS406633BK160S | PB-6X6mm-Blue
 | TS40-66-33-BK-160-SMT-TR | SE PUSHBUTTON | B2 | 1 | Same Sky | TS40-66-33-BK-160-SMT-TR | Mouser | 179-TS406633BK160S | PB-6X6mm-Black
 | 10u | Tantalum Capacitor | C27, C56 | 2 | Vishay | TR3B106K016C0500 | Mouser | 74-TR3B106K016C0500 | TAN-B
 | PJ-002A | Through Hole Right Angle DC Power Jack, 2.5 A, 2 mm Center Pin, 3 Position, -25 to 85 degC, RoHS, Bulk | J5 | 1 | Same Sky | PJ-002A | DigiKey | CP-002A-ND | CUI-PJ-002A_V
 | 61302021121 | THT Vertical Pin Header WR-PHD, Pitch 2.54 mm, Dual Row, 20 pins | P2 | 1 | Wurth Elektronik | 61302021121 | DigiKey | 732-5301-ND | 61302021121
 | ESDA6V1BC6 | TVS DIODE 5V SOT23-6 | D1 | 1 | STMicroelectronics | ESDA6V1BC6 | Future Electronics | ESDA6V1BC6 | FP-SOT23-6L-MFG
 | Red | Typical RED, GREEN, YELLOW, AMBER GaAs LED | LD1 | 1 | Wurth Elektronik | 150160RS73103 | Mouser | 710-150160RS73103 | 0603D-R
 | Blue | Typical RED, GREEN, YELLOW, AMBER GaAs LED | LD2 | 1 | Wurth Elektronik | 150160BS73103 | DigiKey | 732-150160BS73103DKR-ND | 0603D-B
 | Green | Typical RED, GREEN, YELLOW, AMBER GaAs LED | LD3, LD5, LD6 | 3 | Wurth Elektronik | 150060VS83000 | Mouser | 710-150060VS83000 | 0603D-G
 | PESD2CANFD24LT-QR | vp_PESD2CANFD24LT-Q - ESD protection for In-vehicle networks@en-us | D2_1, D2_2 | 2 | Nexperia | PESD2CANFD24LT-QR | DigiKey | 1727-PESD2CANFD24LT-QRCT-ND | SOT95P230X110-3N

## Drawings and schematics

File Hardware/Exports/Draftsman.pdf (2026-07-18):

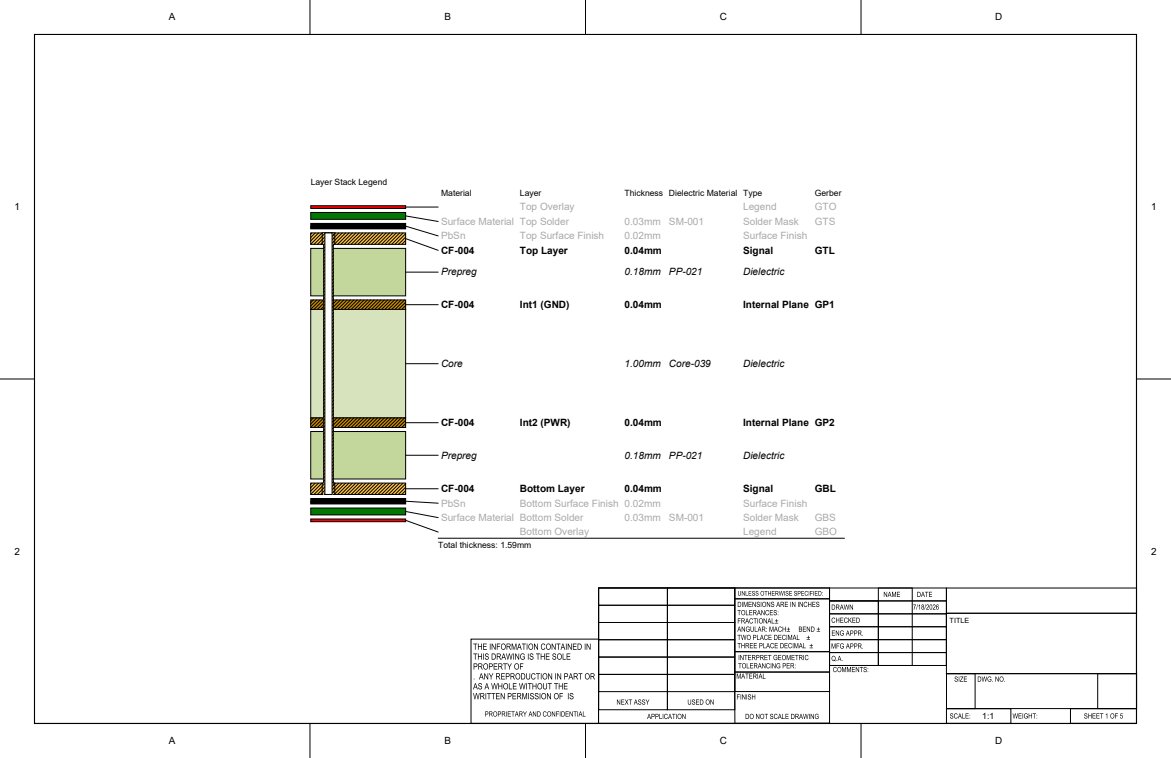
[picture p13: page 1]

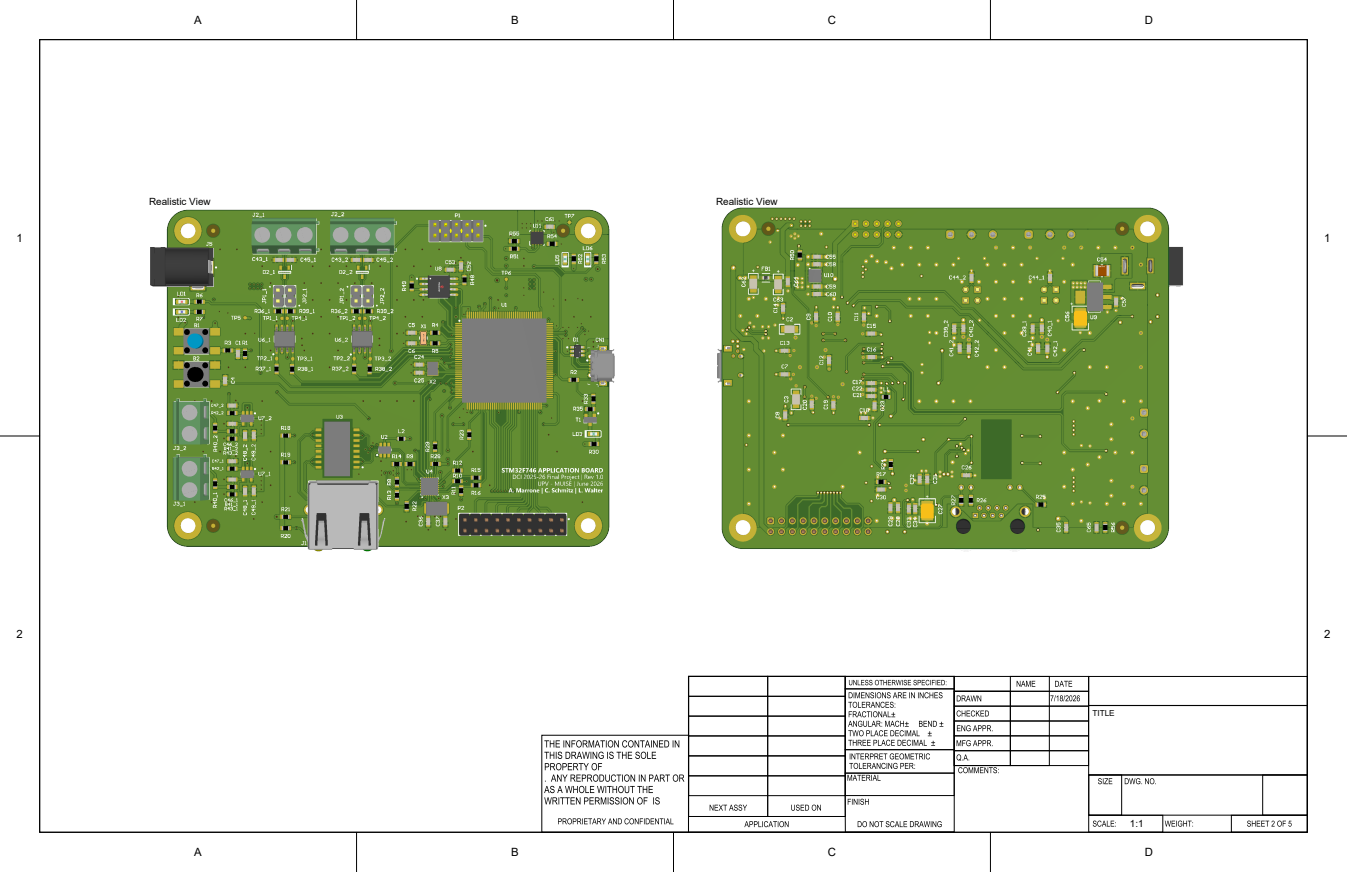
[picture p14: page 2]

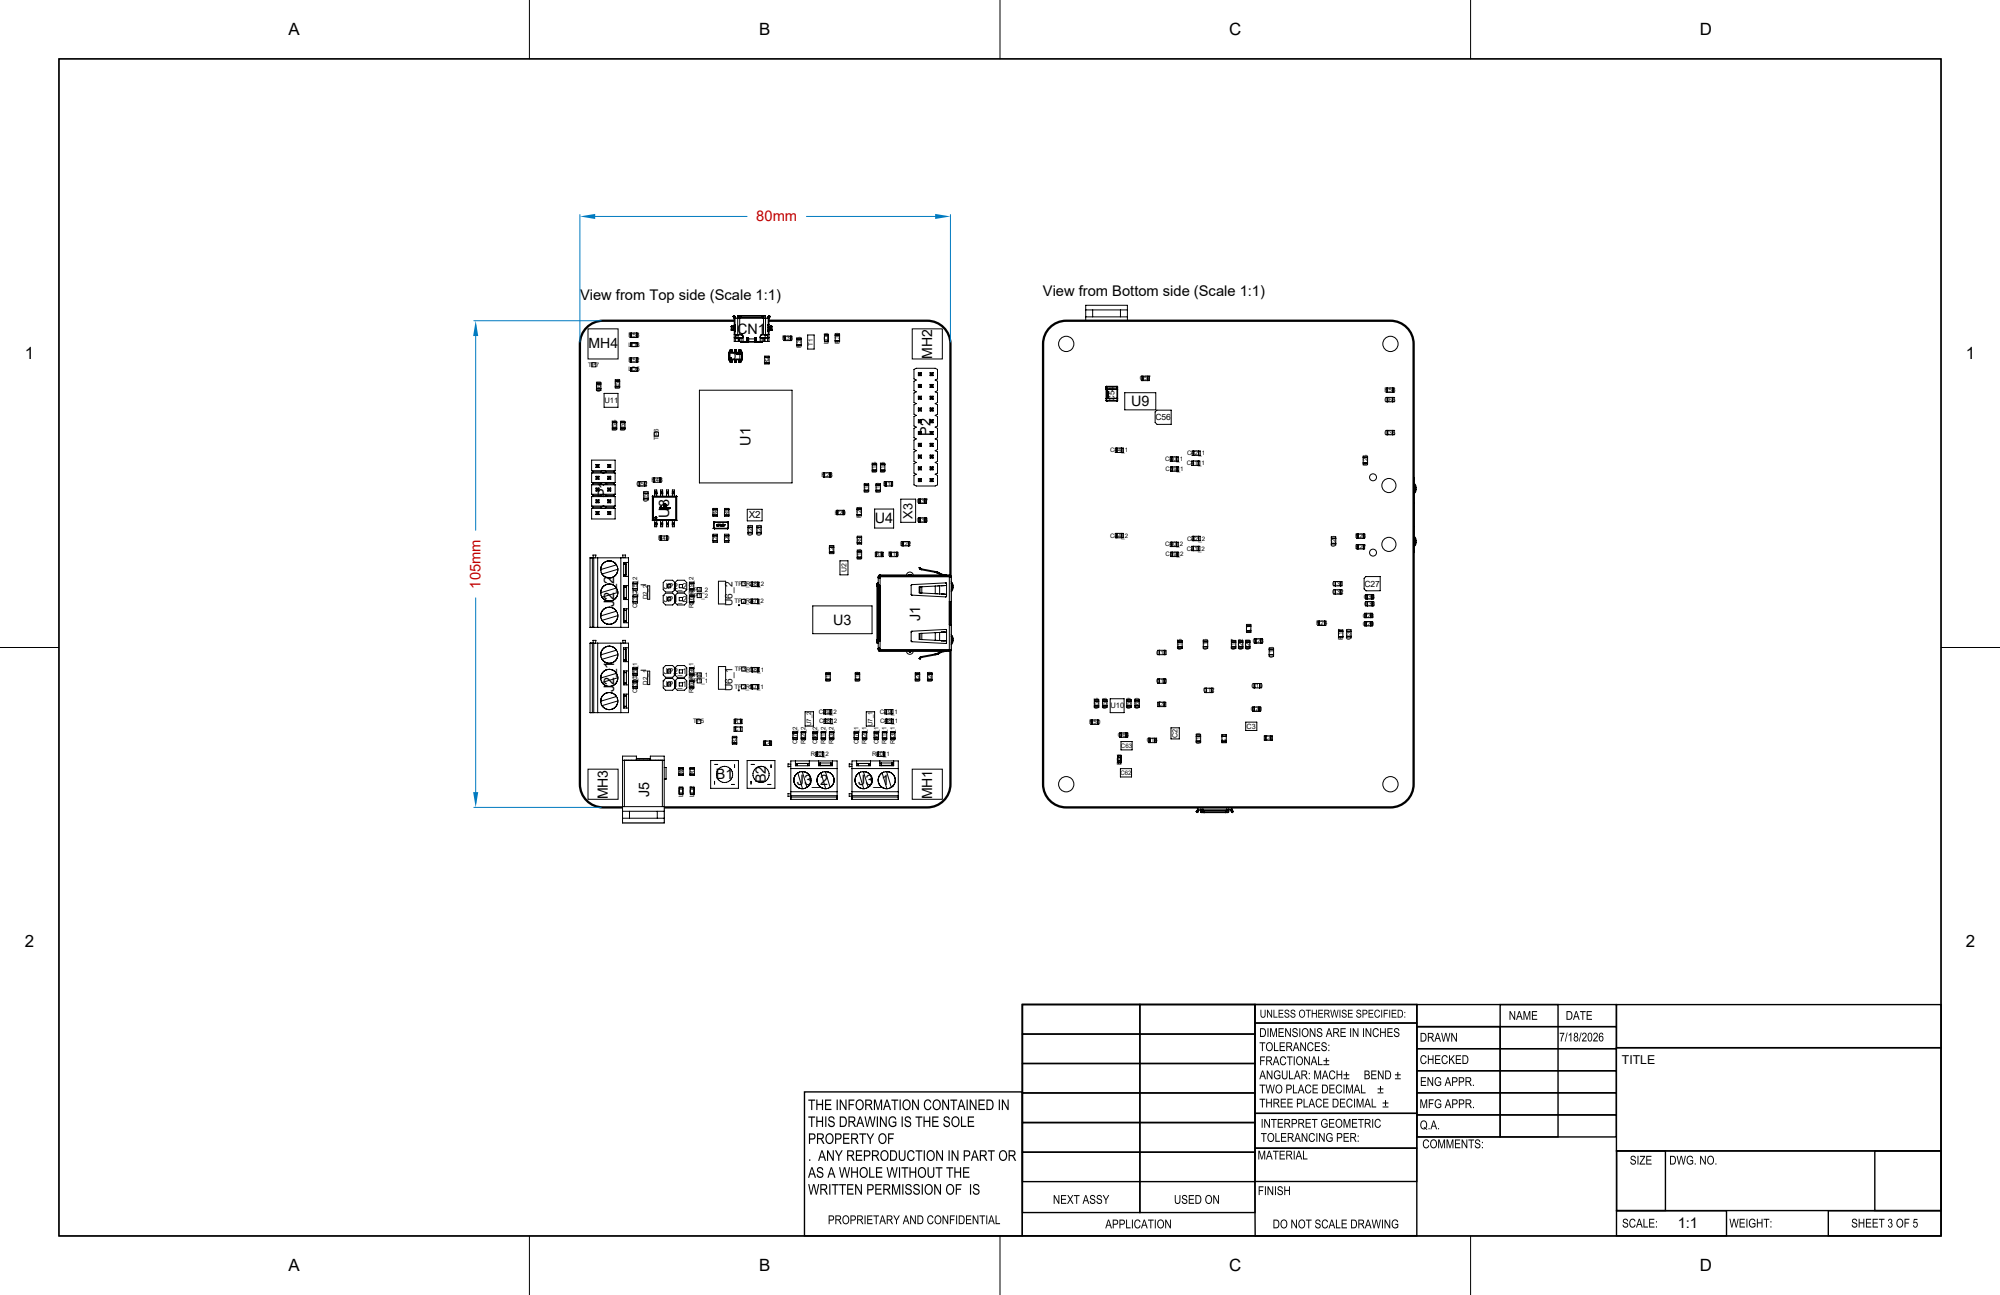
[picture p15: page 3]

View from Top side (Scale 1:1)

View from Bottom side (Scale 1:1)

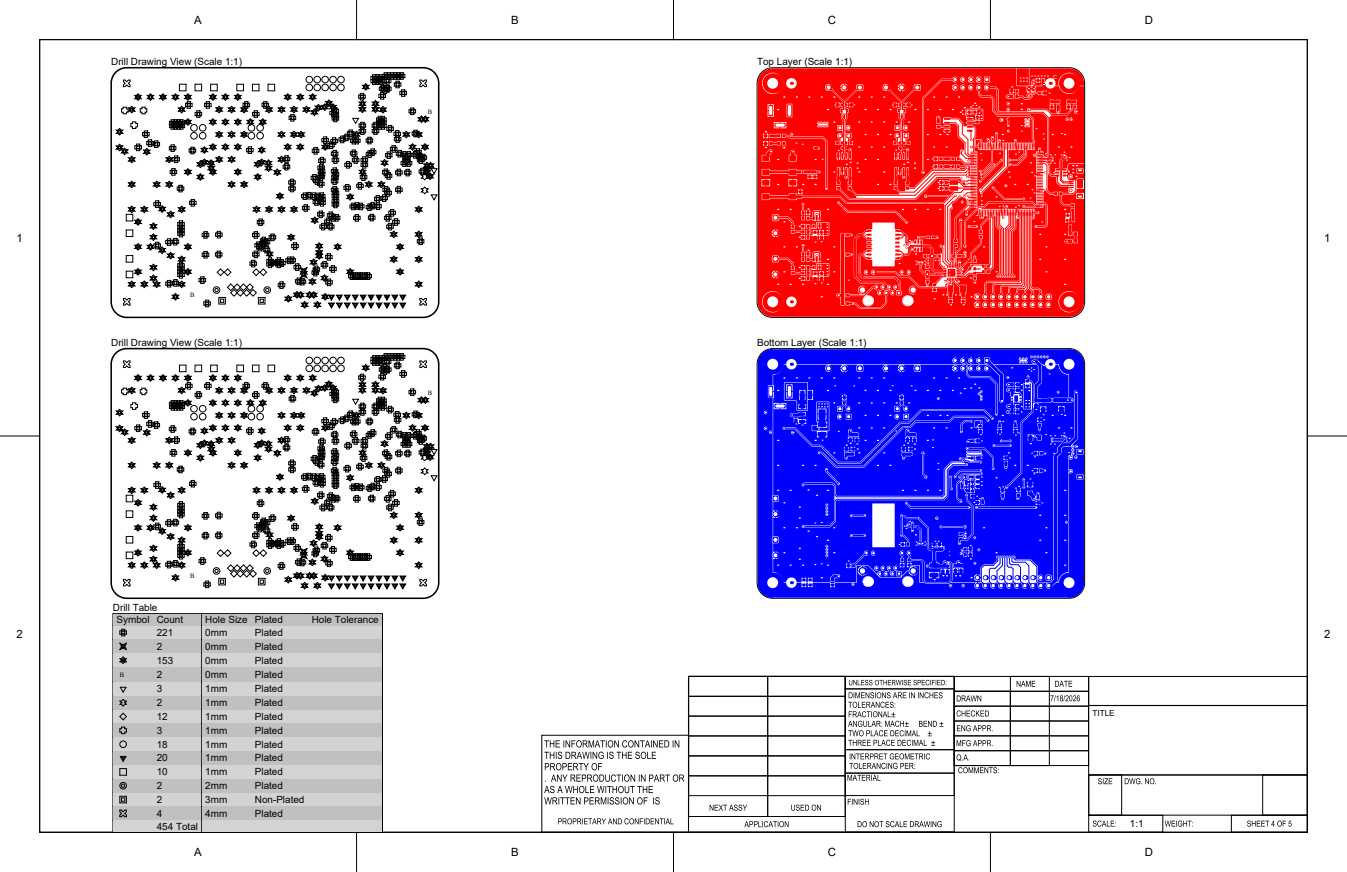
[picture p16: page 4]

Drill Drawing View (Scale 1:1)

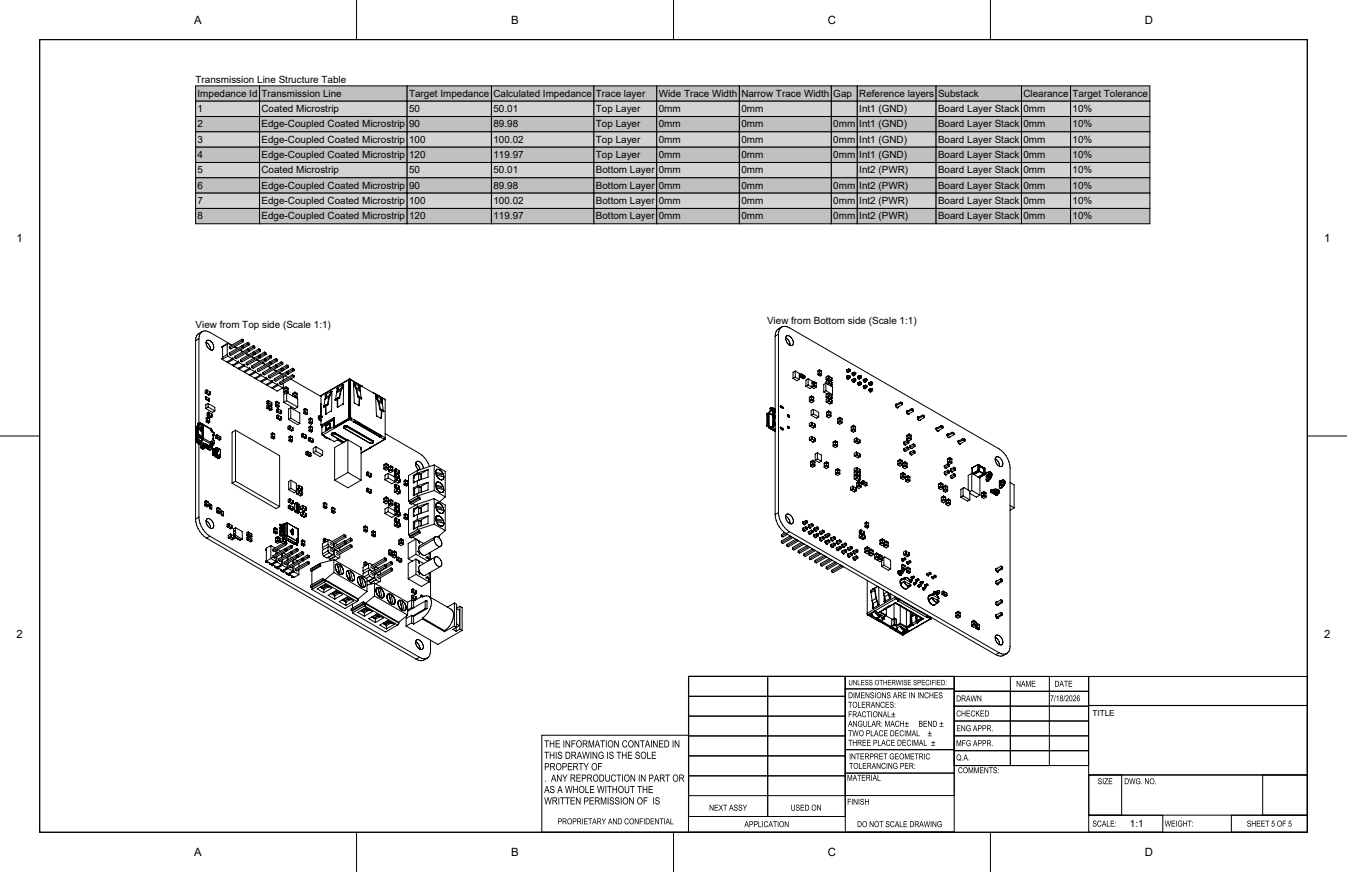
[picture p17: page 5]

Transmission Line Structure Table

Impedance Id | Transmission Line | Target Impedance | Calculated Impedance | Trace layer | Wide Trace Width | Narrow Trace Width | Gap | Reference layers | Substack | Clearance | Target Tolerance
1 | Coated Microstrip | 50 | 50.01 | Top Layer | 0mm | 0mm | | Int1 (GND) | Board Layer Stack | 0mm | 10%
2 | Edge-Coupled Coated Microstrip | 90 | 89.98 | Top Layer | 0mm | 0mm | 0mm | Int1 (GND) | Board Layer Stack | 0mm | 10%
3 | Edge-Coupled Coated Microstrip | 100 | 100.02 | Top Layer | 0mm | 0mm | 0mm | Int1 (GND) | Board Layer Stack | 0mm | 10%
4 | Edge-Coupled Coated Microstrip | 120 | 119.97 | Top Layer | 0mm | 0mm | 0mm | Int1 (GND) | Board Layer Stack | 0mm | 10%
5 | Coated Microstrip | 50 | 50.01 | Bottom Layer | 0mm | 0mm | | Int2 (PWR) | Board Layer Stack | 0mm | 10%
6 | Edge-Coupled Coated Microstrip | 90 | 89.98 | Bottom Layer | 0mm | 0mm | 0mm | Int2 (PWR) | Board Layer Stack | 0mm | 10%
7 | Edge-Coupled Coated Microstrip | 100 | 100.02 | Bottom Layer | 0mm | 0mm | 0mm | Int2 (PWR) | Board Layer Stack | 0mm | 10%
8 | Edge-Coupled Coated Microstrip | 120 | 119.97 | Bottom Layer | 0mm | 0mm | 0mm | Int2 (PWR) | Board Layer Stack | 0mm | 10%

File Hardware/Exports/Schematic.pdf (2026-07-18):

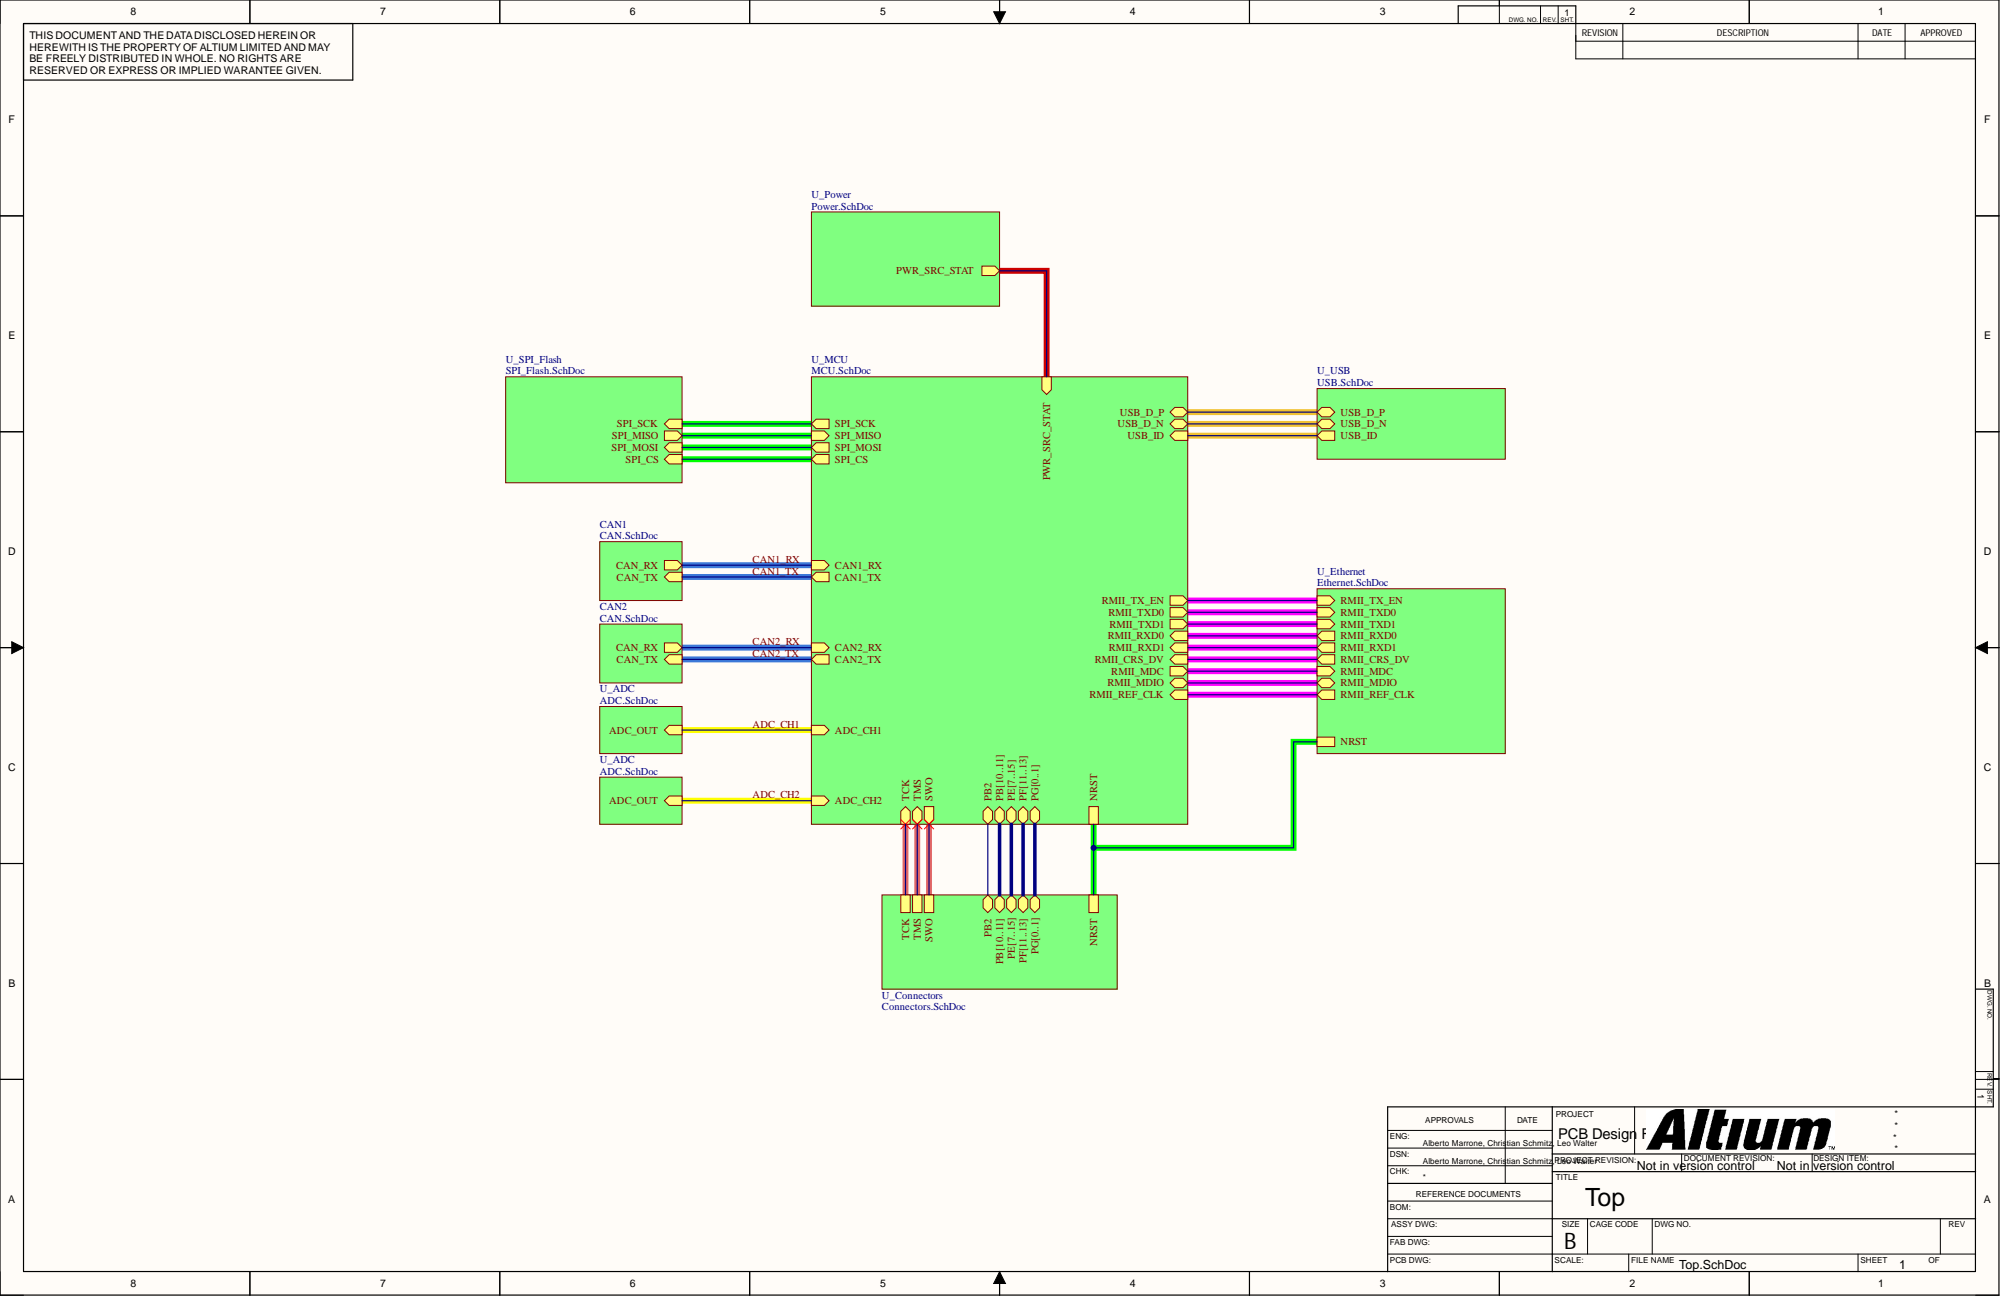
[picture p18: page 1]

DWG. NO. | REV. | SHT.

THIS DOCUMENT AND THE DATA DISCLOSED HEREIN OR HEREWITH IS THE PROPERTY OF ALTIUM LIMITED AND MAY BE FREELY DISTRIBUTED IN WHOLE. NO RIGHTS ARE RESERVED OR EXPRESS OR IMPLIED WARANTEE GIVEN. | U_Power Power.SchDoc | REVISION | DESCRIPTION | DATE | APPROVED

REV. SHT. DWG. NO.

DATE | PROJECT PCB Design Final Project | * * APPROVALS * *

ENG: Alberto Marrone, Christian Schmitz, Leo Walter

DSN:

Alberto Marrone, Christian Schmitz, Leo Walter

PROJECT REVISION: Not in version control | DOCUMENT REVISION: Not in | DESIGN ITEM: version control

CHK: *

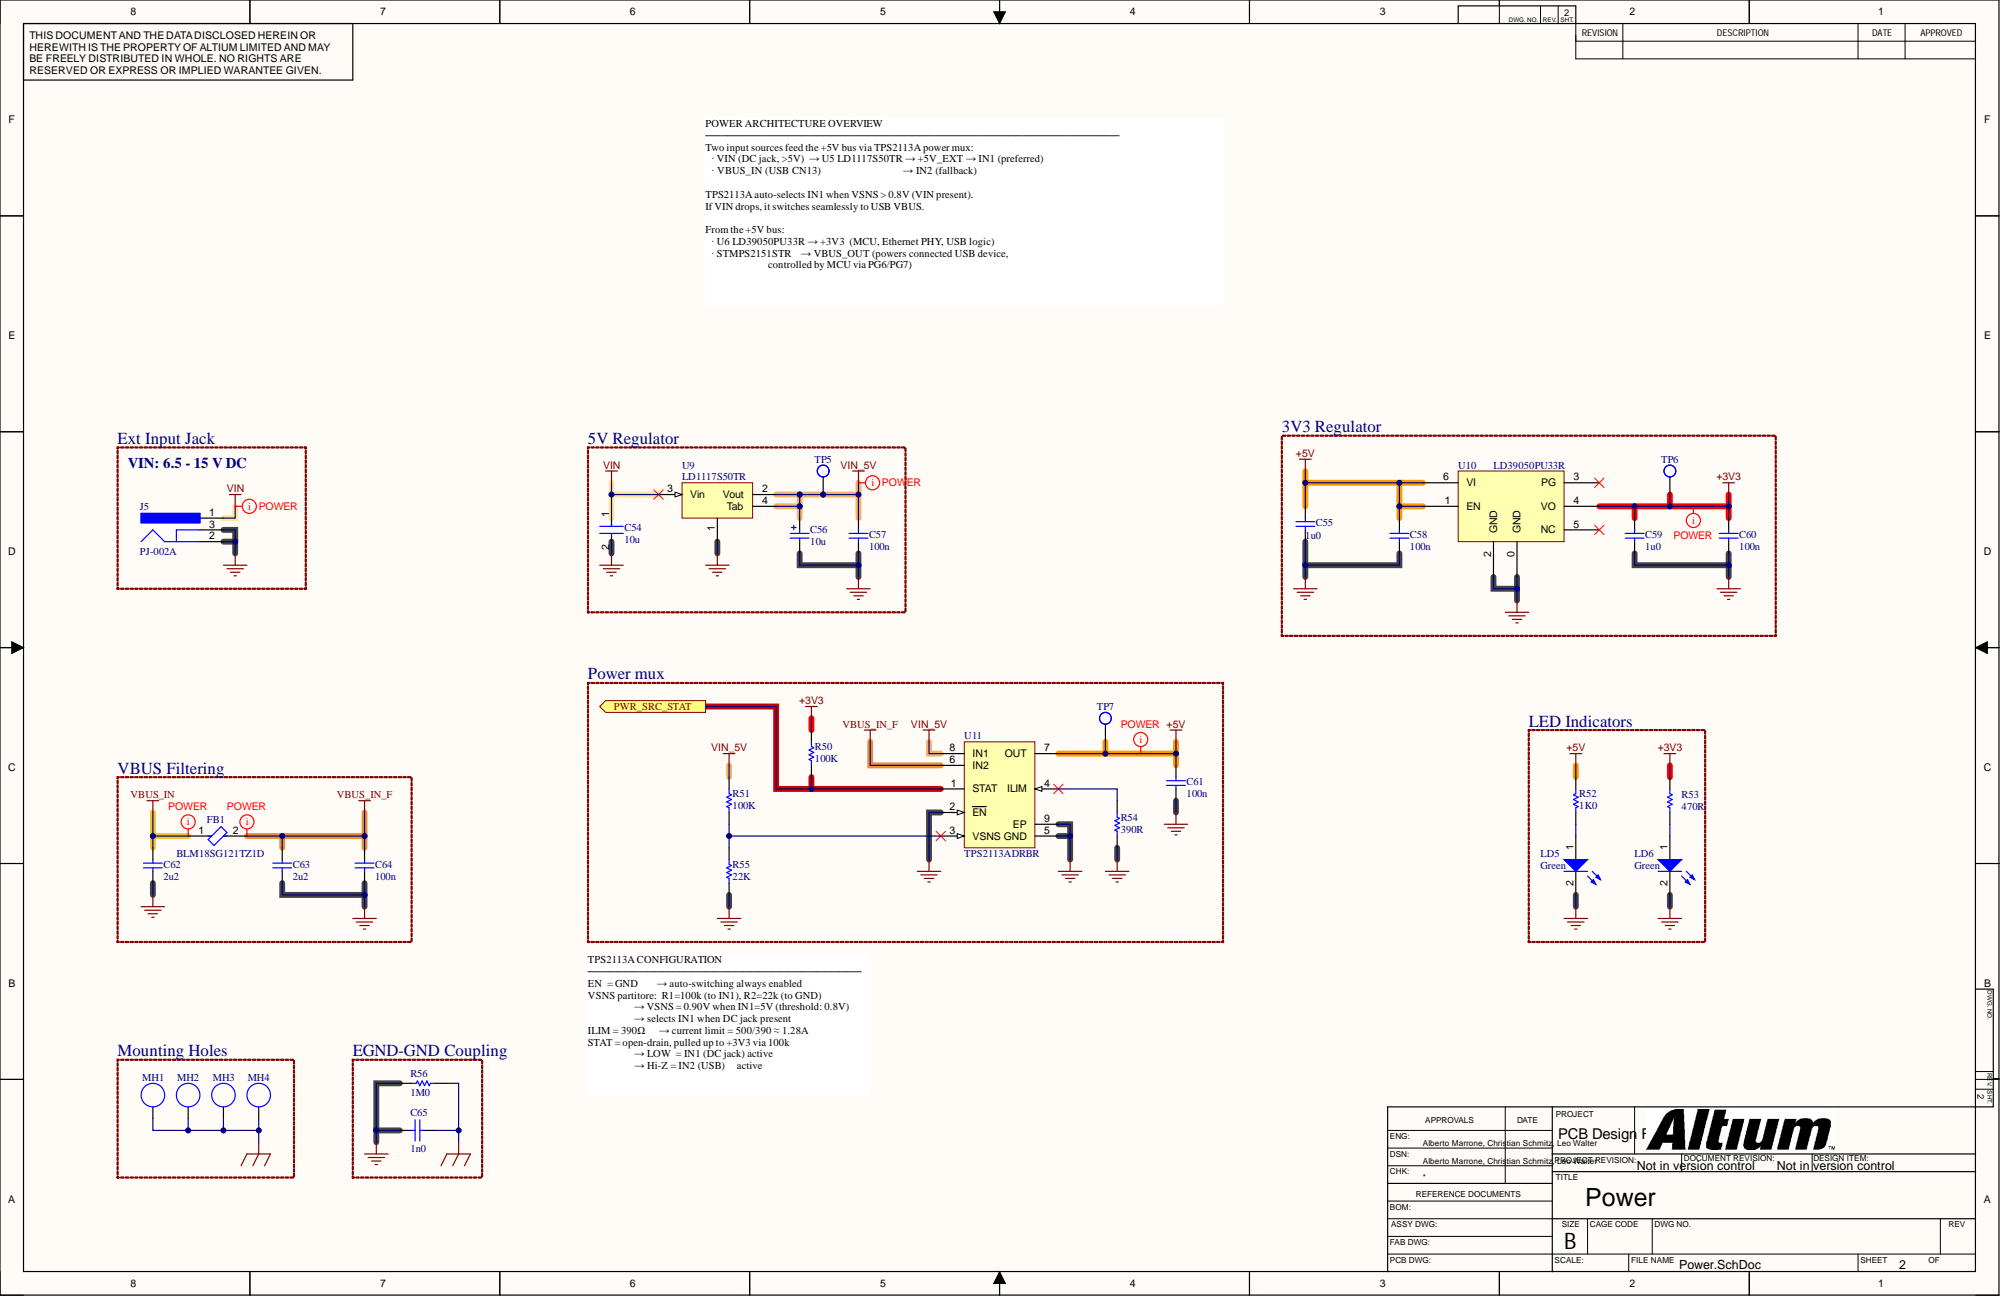
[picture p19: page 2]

POWER ARCHITECTURE OVERVIEW
Two input sourcesfeed the +5V bus via TPS2113A power mux:
· VIN (DC jack, >5V) → U5 LD1117S50TR → +5V_EXT → IN1 (preferred)

TPS2113A auto-selects IN1 when VSNS > 0.8V (VIN present).
If VIN drops, it switches seamlessly to USB VBUS.

From the +5V bus:
· U6 LD39050PU33R → +3V3 (MCU, Ethernet PHY, USB logic)
· STMPS2151STR → VBUS_OUT (powers connected USB device,

controlled by MCU via PG6/PG7)

TPS2113A CONFIGURATION
VSNS partitore: R1=100k (to IN1), R2=22k (to GND)

REV. SHT. DWG. NO.

→ VSNS = 0.90V when IN1=5V (threshold: 0.8V)
→ selects IN1 when DC jack present

STAT = open-drain, pulled up to +3V3 via 100k

→ LOW = IN1 (DC jack) active

APPROVALS | DATE | PROJECT PCB Design Final Project

ENG: Alberto Marrone, Christian Schmitz, Leo Walter

DSN:

Alberto Marrone, Christian Schmitz, Leo Walter

PROJECT REVISION: Not in version control | DOCUMENT REVISION: Not in | DESIGN ITEM: version control

CHK: *

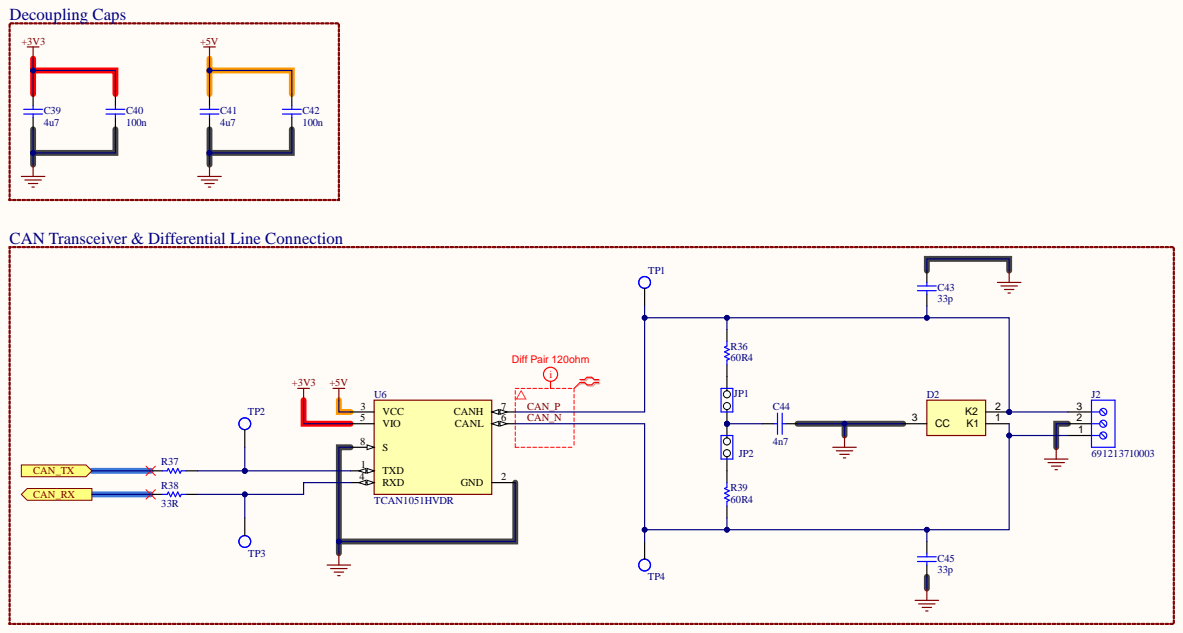
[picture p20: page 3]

DWG . N | R E V | S H T.

T IS DOC U MEN T AN D HE ATA ISCLOSED HEREI N OR HEREW I HE PROPER TY OF ALT M LI M TED AN AY BE F REELY IST IBU TED W HOLE. NO IGH TS ARE RESERVED OR EXPRESS OR MPLIED WARAN TEE GIVEN | u plin g Cap V V | REVISI ON | DESCRIPTI O N | DATE | APPROVED

Transceiver & Differential Line Co

REV. SHT. DWG. NO.

DATE | PRO JECT PCB Design Final Project e o W a lte r | **** APPROVALS

ENG : Al b erto M arro n e, Chri | sti a n Sc h m itz, L

DSN: Al b erto M arro n e, Chri | sti a n Sc h m

CHK: *

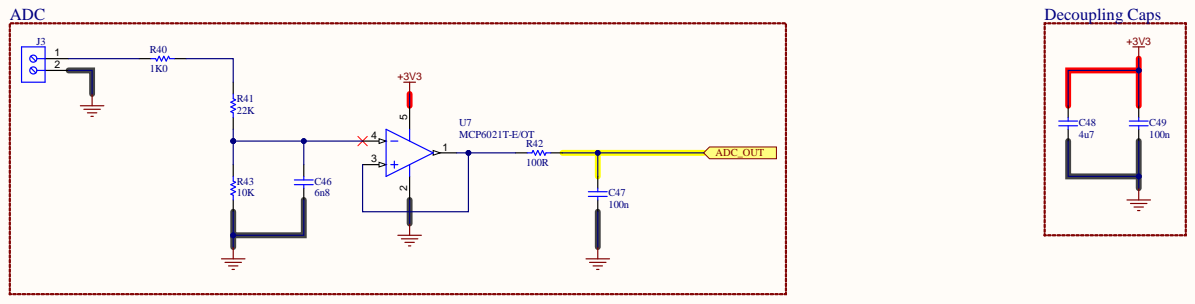
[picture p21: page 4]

REV. SHT. DWG. NO.

DATE | PRO JECT PCB Design Final Project e o W a lte r | **** APPROVALS

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

DSN: Al b erto M arro n e, Chri | sti a n Sc h m

CHK: *

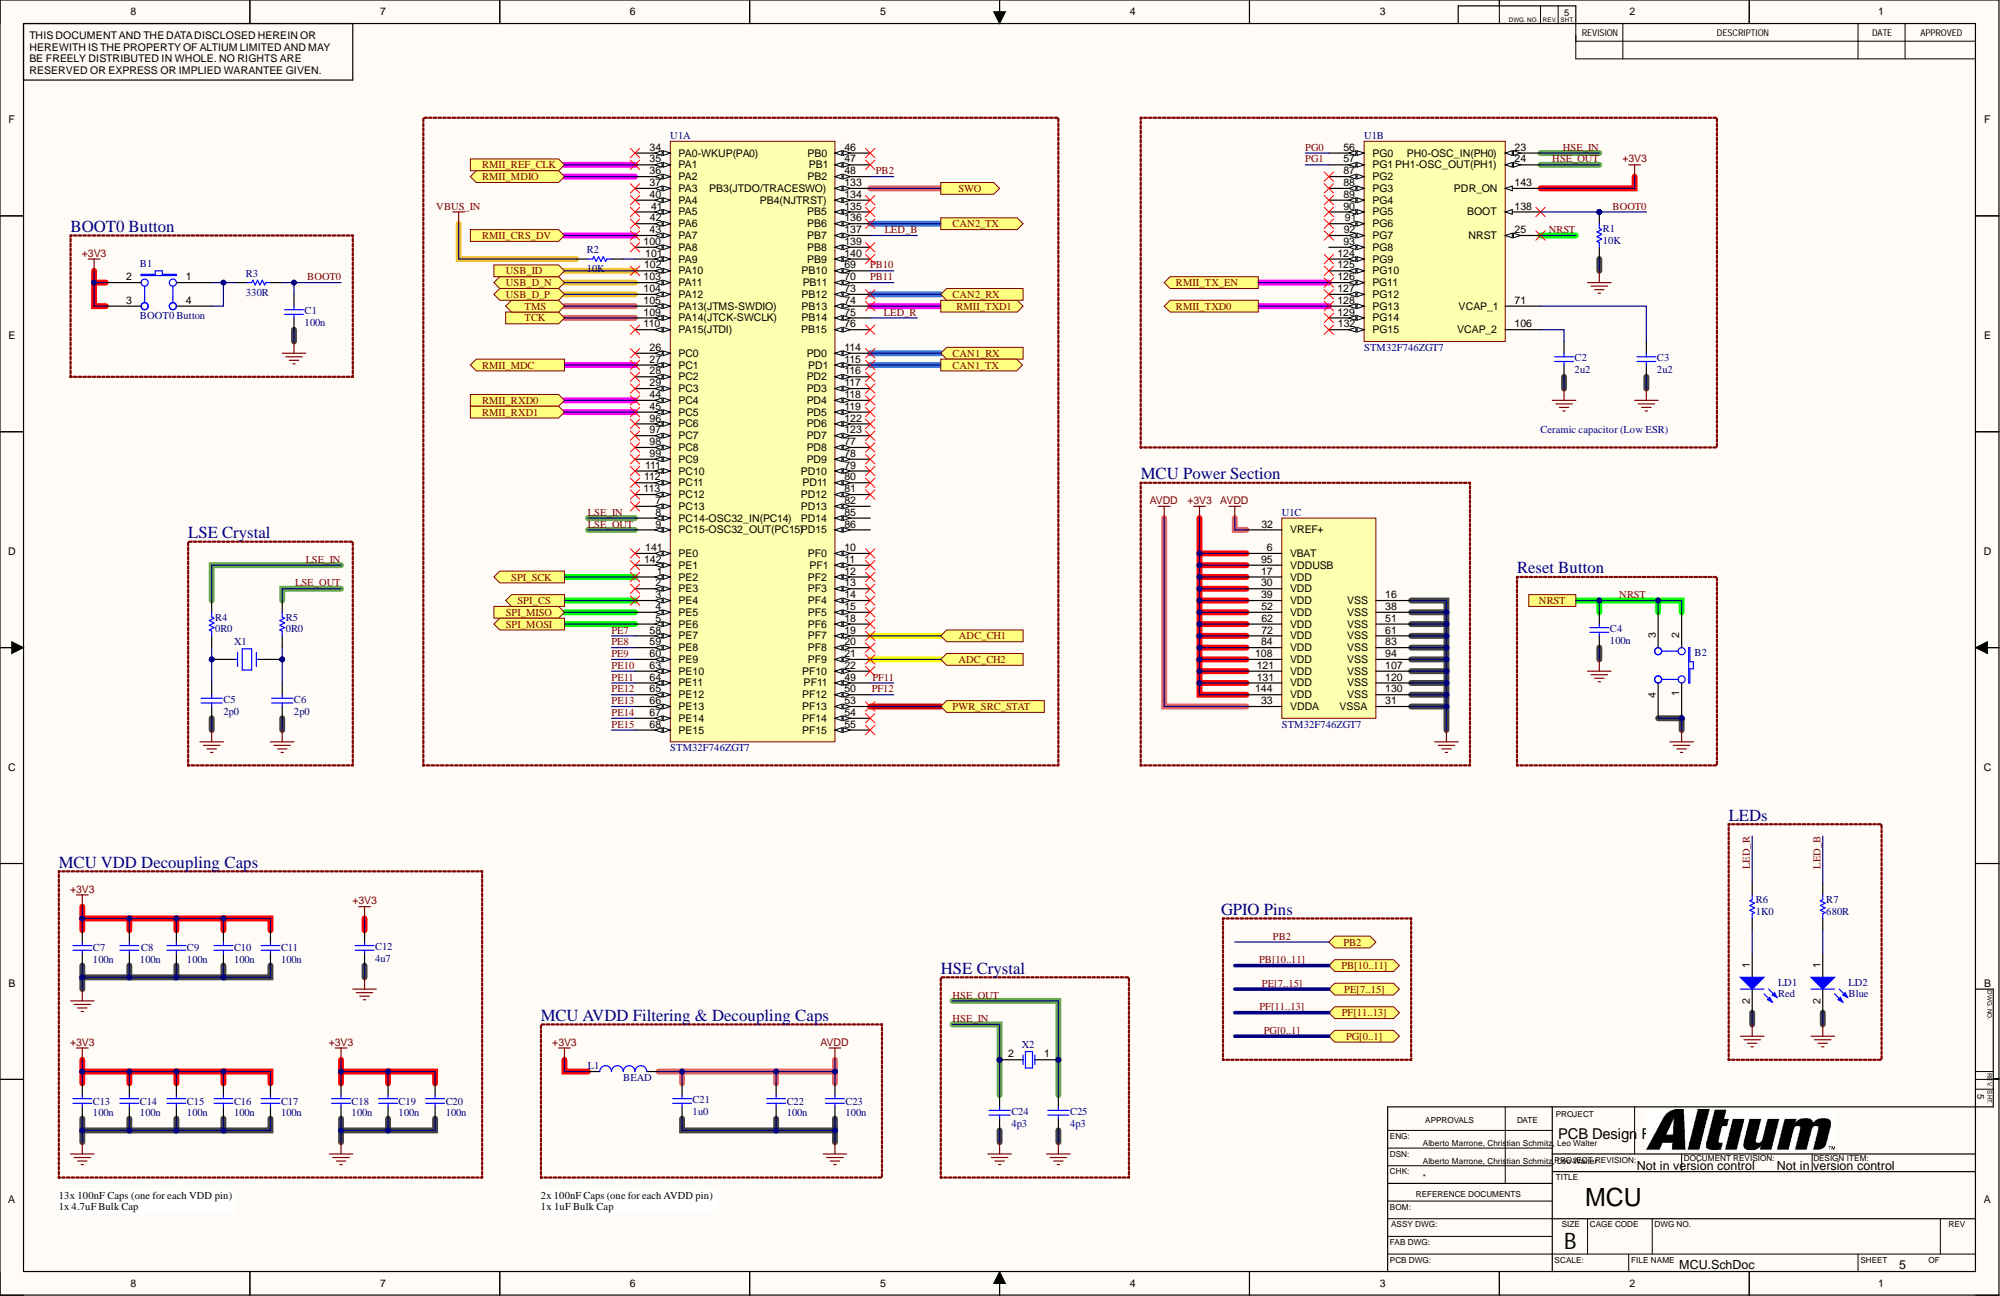
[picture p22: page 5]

Ceramic capacitor (Low ESR)

MCU VDD Decoupling Caps

REV. SHT. DWG. NO.

MCU AVDD Filtering & Decoupling Caps

APPROVALS | DATE | PROJECT PCB Design Final Project

ENG: Alberto Marrone, Christian Schmitz, Leo Walter

DSN:

Alberto Marrone, Christian Schmitz, Leo Walter

PROJECT REVISION: Not in version control | DOCUMENT REVISION: Not in | DESIGN ITEM: version control

CHK: *

13x 100nF Caps (one for each VDD pin)
1x 4.7uF Bulk Cap

2x 100nF Caps (one for each AVDD pin)
1x 1uF Bulk Cap

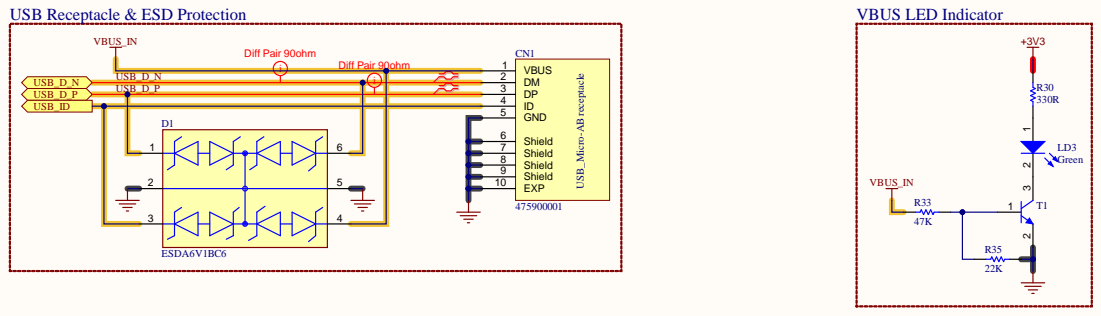
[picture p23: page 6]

USB Receptacle & ESD Protectio

REV. SHT. DWG. NO.

DATE | PRO JECT PCB Design Final Project e o W a lte r | **** APPROVALS

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

DSN: Al b erto M arro n e, Chri | sti a n Sc h m

CHK: *

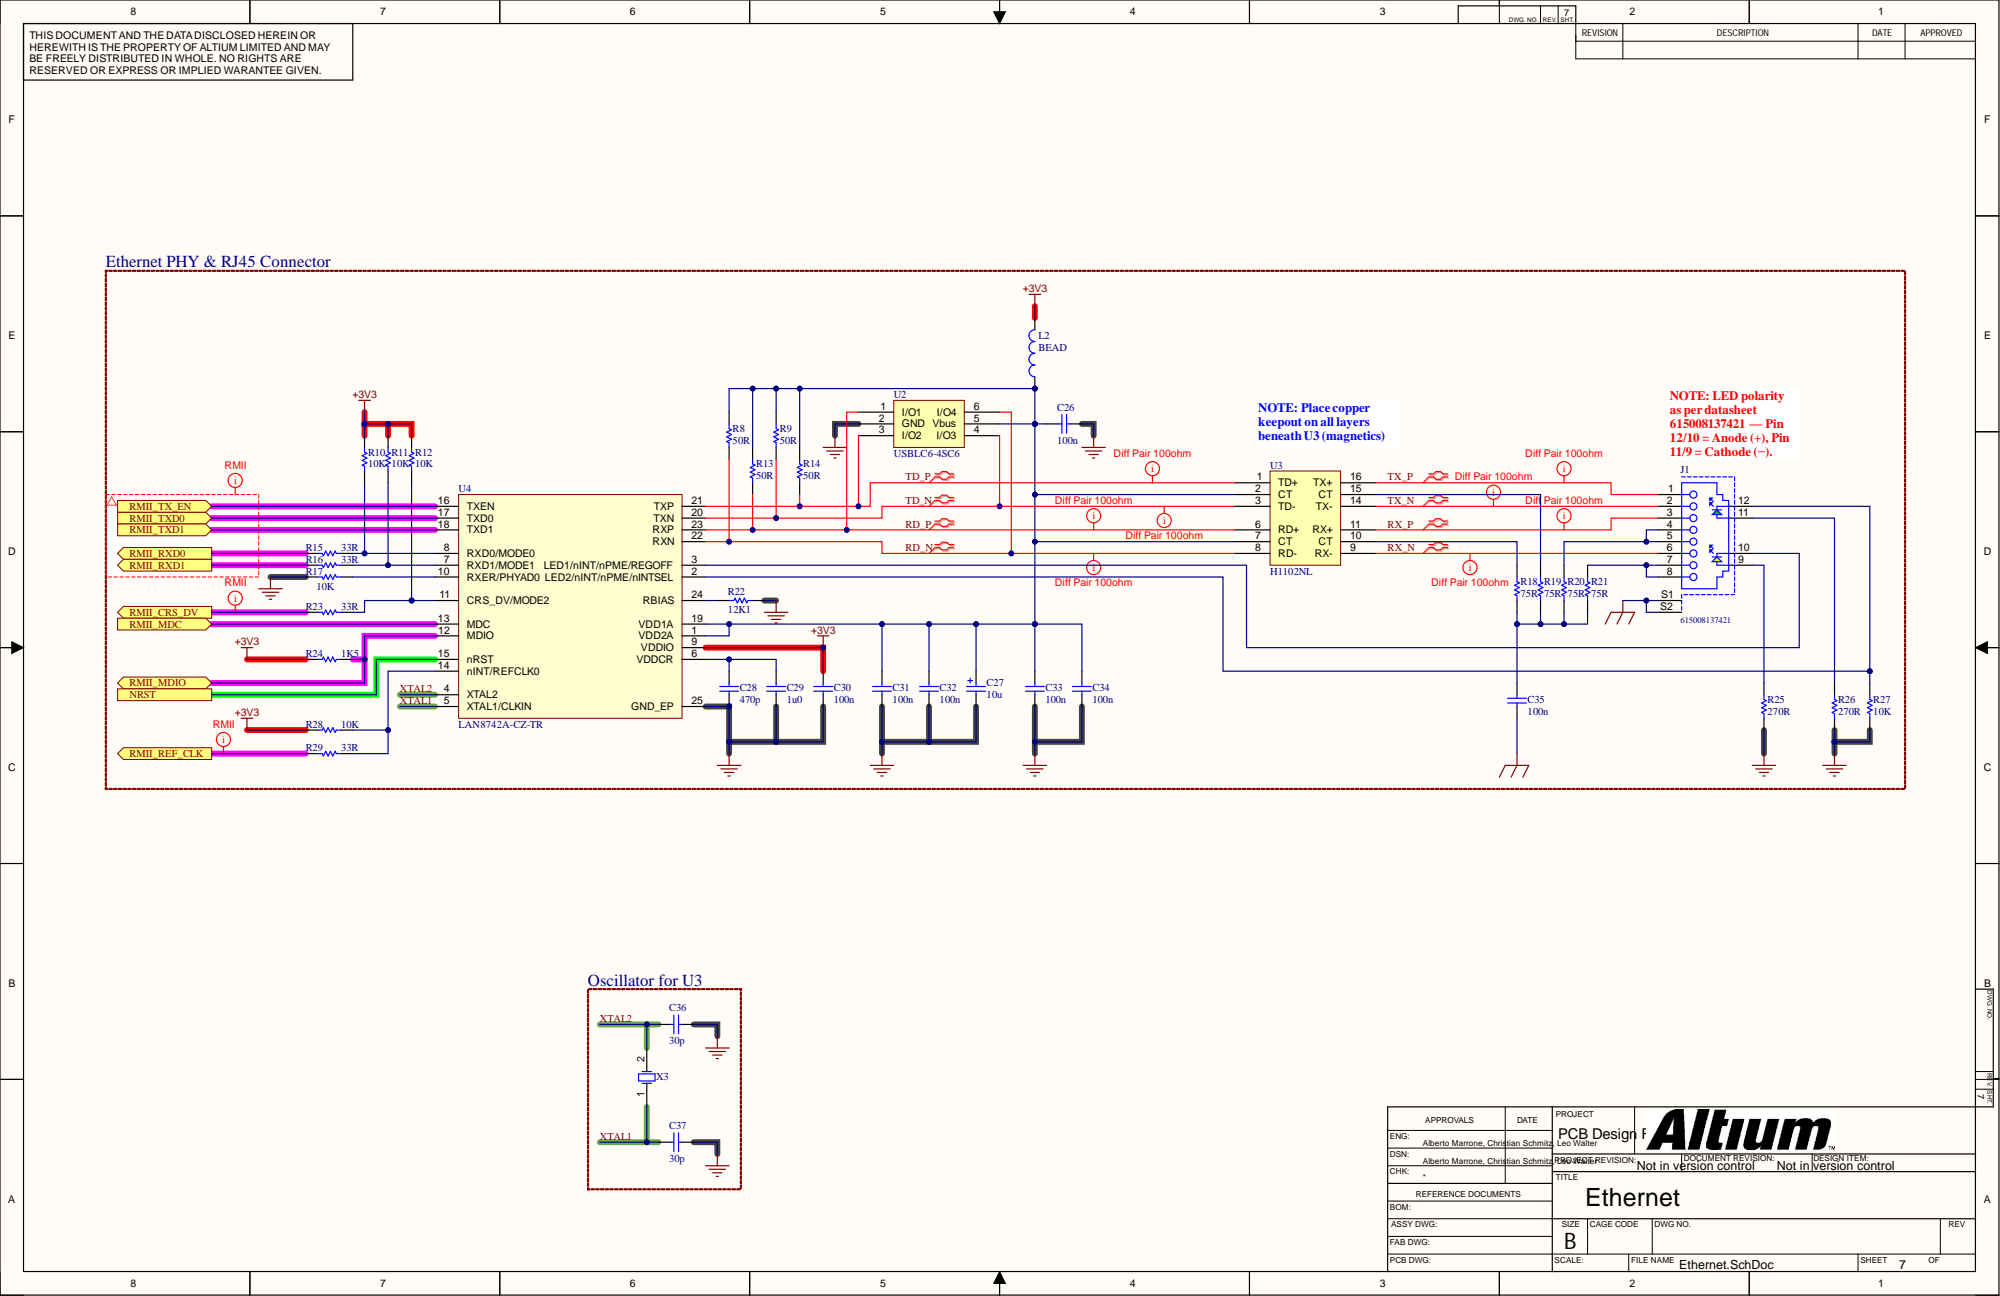
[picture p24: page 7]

NOTE: Place copper
keepout on all layers
beneath U3 (magnetics)

nINT/REFCLK0 14

XTAL2

REV. SHT. DWG. NO.

APPROVALS | DATE | PROJECT PCB Design Final Project

ENG: Alberto Marrone, Christian Schmitz, Leo Walter

DSN:

Alberto Marrone, Christian Schmitz, Leo Walter

PROJECT REVISION: Not in version control | DOCUMENT REVISION: Not in | DESIGN ITEM: version control

CHK: *


REV. SHT. DWG. NO.

DATE | PRO JECT PCB Design Final Project e o W a lte r | **** APPROVALS

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

DSN: Al b erto M arro n e, Chri | sti a n Sc h m

CHK: *


REV. SHT. DWG. NO.

APPRO VAL S | DATE | PRO JECT PCB Design Final Project e o W a lte r

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

DSN: Al b erto M arro n e, Chri | sti a n Sc h m

CHK: *

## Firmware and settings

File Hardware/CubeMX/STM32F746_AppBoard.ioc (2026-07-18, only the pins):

Mcu.UserName=STM32F746ZGTx
PA1.Signal=ETH_REF_CLK
PA10.Signal=USB_OTG_FS_ID
PA11.Signal=USB_OTG_FS_DM
PA12.Signal=USB_OTG_FS_DP
PA13.Signal=SYS_JTMS-SWDIO
PA14.Signal=SYS_JTCK-SWCLK
PA2.Signal=ETH_MDIO
PA7.Signal=ETH_CRS_DV
PA9.Signal=USB_OTG_FS_VBUS
PB10.Signal=GPIO_Input
PB11.Signal=GPIO_Input
PB12.Signal=CAN2_RX
PB13.Signal=ETH_TXD1
PB14.GPIO_Label=LED_R
PB14.Signal=GPIO_Output
PB2.Signal=GPIO_Input
PB3.Signal=SYS_JTDO-SWO
PB6.Signal=CAN2_TX
PB7.GPIO_Label=LED_B
PB7.Signal=GPIO_Output
PC1.Signal=ETH_MDC
PC14/OSC32_IN.Signal=RCC_OSC32_IN
PC15/OSC32_OUT.Signal=RCC_OSC32_OUT
PC4.Signal=ETH_RXD0
PC5.Signal=ETH_RXD1
PD0.Signal=CAN1_RX
PD1.Signal=CAN1_TX
PE10.Signal=GPIO_Input
PE11.Signal=GPIO_Input
PE12.Signal=GPIO_Input
PE13.Signal=GPIO_Input
PE14.Signal=GPIO_Input
PE15.Signal=GPIO_Input
PE2.Signal=SPI4_SCK
PE4.GPIO_Label=SPI4_CS
PE4.Signal=GPIO_Output
PE5.Signal=SPI4_MISO
PE6.Signal=SPI4_MOSI
PE7.Signal=GPIO_Input
PE8.Signal=GPIO_Input
PE9.Signal=GPIO_Input
PF11.Signal=GPIO_Input
PF12.Signal=GPIO_Input
PF13.GPIO_Label=PWR_SRC_STAT
PF13.Signal=GPIO_Input
PF7.Signal=ADC3_IN5
PF9.Signal=ADC3_IN7
PG0.Signal=GPIO_Input
PG1.Signal=GPIO_Input
PG11.Signal=ETH_TX_EN
PG13.Signal=ETH_TXD0
PH0/OSC_IN.Signal=RCC_OSC_IN
PH1/OSC_OUT.Signal=RCC_OSC_OUT

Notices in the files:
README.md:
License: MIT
